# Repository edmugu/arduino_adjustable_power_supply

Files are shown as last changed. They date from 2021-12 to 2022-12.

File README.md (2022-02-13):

---
title: Intro
nav_order: 1
description: "Just the Docs is a responsive Jekyll theme with built-in search that is easily customizable and hosted on GitHub Pages."
permalink: /
---

# [Arduino Power Supply](https://edmugu.github.io/arduino_adjustable_power_supply/)

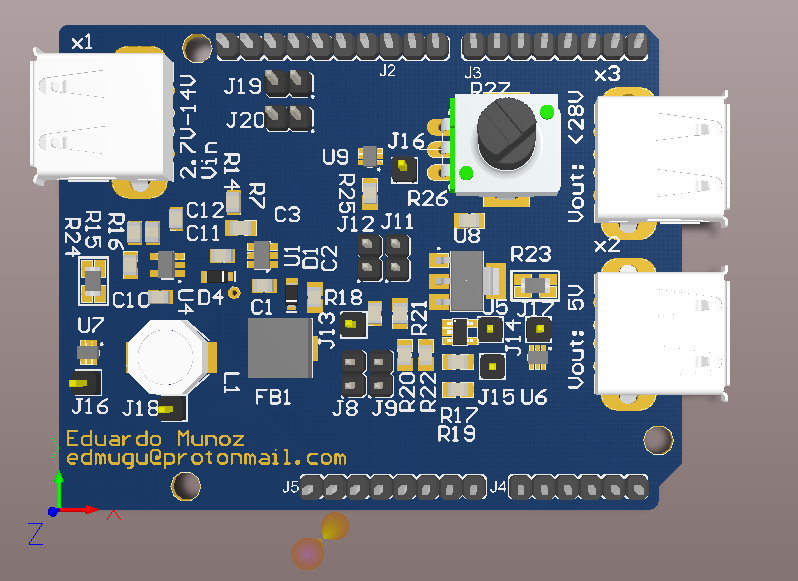
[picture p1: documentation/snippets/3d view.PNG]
3d view of pcb file Power Supply


link to Jekyll readme: https://edmugu.github.io/arduino_adjustable_power_supply/

## Abstract

This project is based on the [LT journal's Article from Keith Szolusha](https://github.com/edmugu/arduino_adjustable_power_supply/blob/master/documentation/LTJournal-Bench_Supply.pdf). In the article, he discussed how to design a clean power supply. However, this design is augmented by making it controllable by an Arduino. Use Cases Include motor controller, high power wireless communication, and benchtop supply.

## Intro

On the original design by Szolusha, there are four modules. (1) a switching regulator that steps down a 10-40V input to an intermediate voltage that is slightly above the output voltage. (2) Linear regulator that "cleans" the output. (3) The current source sets a reference voltage that is not affected by temperature. Lastly, (4) A current sink that helps the Linear regulator reach low voltages.

We will modify each block to fit our needs, making this portable and usable with any common household batteries. So the base design is shown on the diagram below. The first step is to step up the battery's voltage to a usable voltage we can step down. The second step is to step down the voltage to the wanted voltages like 3.3 Volts, 5.0 Volts, and Vout. However, the efficient step-down switches can create "switching ripples" on the output. These ripples aren't a big deal; however, one could use an inefficient LDO regulator if one needs a very clean supply. So will use the step-down switch and regulator to create a clean semi-efficient voltage output as shown on the diagram.

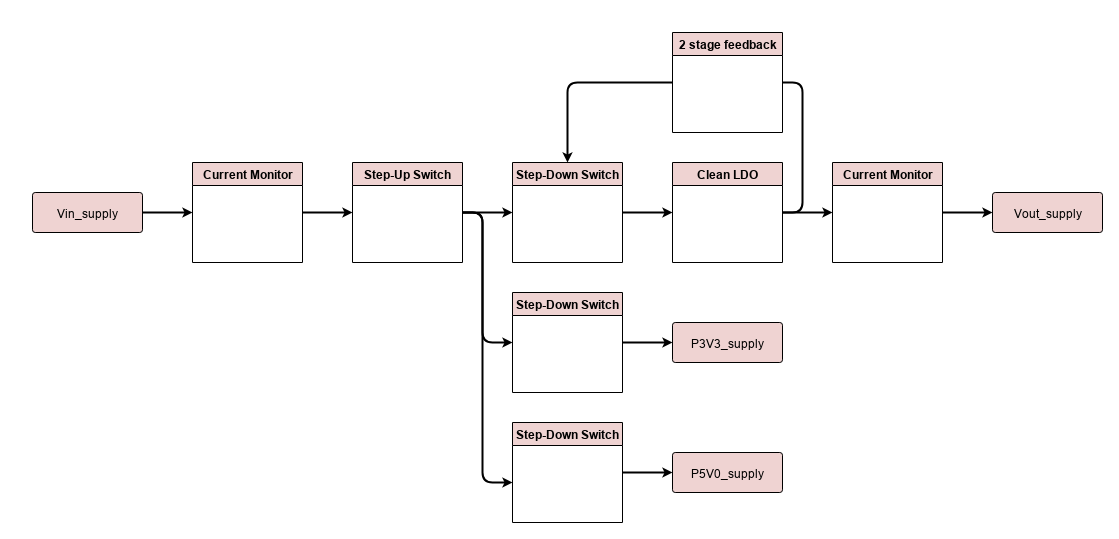
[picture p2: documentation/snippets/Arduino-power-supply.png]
logic schematics


The main target battery is a USB power bank. Most USB power banks can deliver 12W @ 5Volts. Hence, this power supply will deliver 10 Watts at its output to accommodate the inefficiencies of the power stages of this design. Since the default use case will power a 50-ohm load, the maximum voltage at the output should be greater than 22.36 Volts to deliver 10 Watts.

## Disclaimer

I initially was practicing my PCB making skill by testing this "dummy" idea of hooking a 1-amp boost to a 1-amp buck to a 1-amp linear regulator. However, while I was finishing with this PCB of a "dummy" idea that was not really tested, the hardware team I was part of got laid off but I was rehired a few days later. None the less, during those days I though of just manufacturing this PCB and documenting my hardware debugging skills. So there were plenty of bugs on Rev A. Anyhow I am thankful of these series of events, that made me realize how important is to have "demo" projects you can show your future employer.

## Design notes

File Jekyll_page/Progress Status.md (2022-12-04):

---
title: Progress Status
has_children: no
nav_order: 6
---

At the moment I am verifying the the Rev B0 board

2022_12_03: started testing Digital pots and vref.

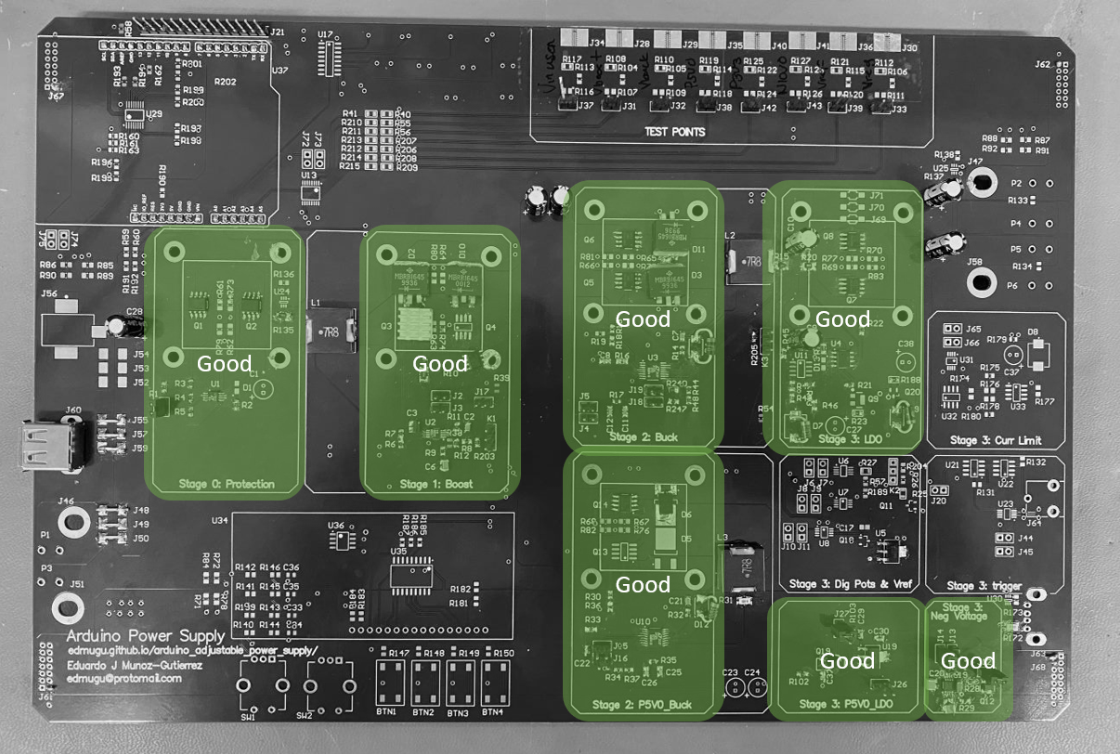
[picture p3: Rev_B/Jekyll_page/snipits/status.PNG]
status diagram


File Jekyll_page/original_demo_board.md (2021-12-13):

---
title: Original_demo_board
has_children: no
nav_order: 5
---

While doing tests on my board, I wanted to compare my design to the reference design shown in the article. So I decided to look for demo boards for the same components used in the article. AND I COULD NOT BELIEVE IT!!! I found the original board still being sold on mouser.com. So I bought one to be able to compare it to my board. Even after getting the board, I was still in denial, the article was written in the summer of 2014, and the demo boards were still being sold in 2021. 

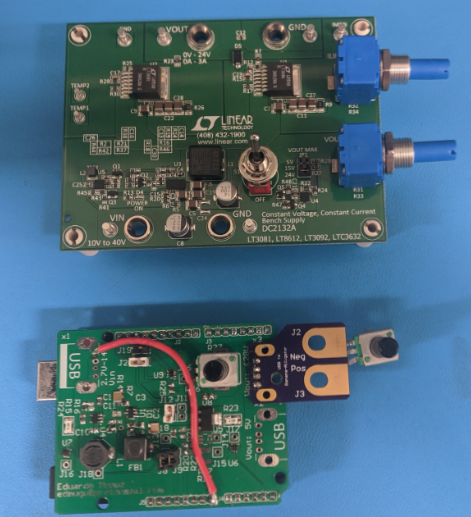
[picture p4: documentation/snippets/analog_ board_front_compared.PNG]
demo board front the front of the demo board


This made me feel great since I was able to tell that Analog Devices needed 3 revisions of this board to get this [simple design] right.

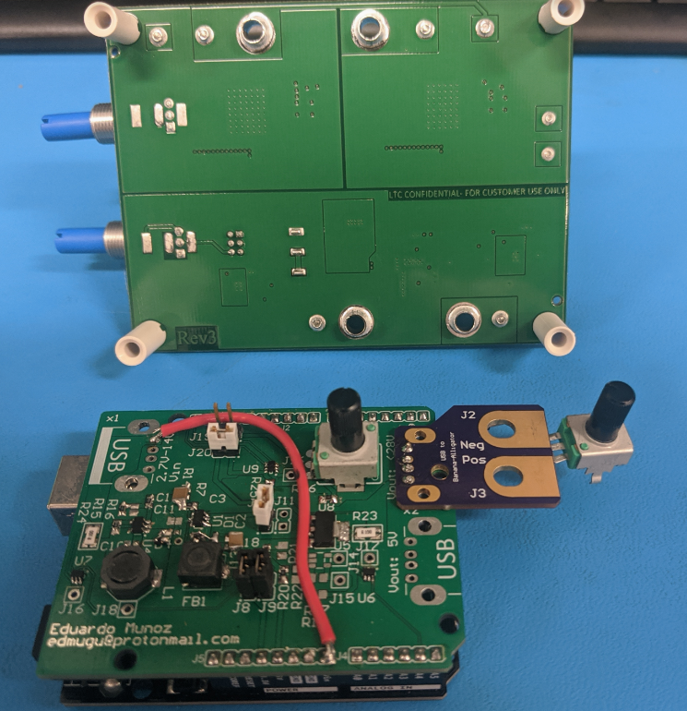
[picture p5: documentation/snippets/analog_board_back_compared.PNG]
demo board back the back of the demo board


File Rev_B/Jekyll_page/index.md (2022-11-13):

---
title: Rev B0
has_children: yes
nav_order: 4
has_toc: false
redirect_to: https://edmugu.github.io/arduino_adjustable_power_supply/Rev.%20B/Jekyll_page/Updates.html
---

This is my second attempt at my power supply, and I corrected the issues described on the "design flaws" and "debugging" pages of rev. A

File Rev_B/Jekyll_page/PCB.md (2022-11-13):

---
layout: default
title: PCB
nav_order: 4
parent: Rev B0
---

# PCB

Before I picked any case, I wanted to "modularize" each stage to know how much space I needed. Also, to get better temperature readings of the MOSFET, it seems that having two MOSFETS in "parallel" would distribute the heat propagated. And a thermal resistor could be placed in between, with some thermal paste; that way, the temperature readings would be more accurate. 
Currently, 2 inches x 2 inches will be good enough per stage [not counting the heat sink area]. So I will probably need a case 10 inches x 4 inches. 

## Thermal sensors

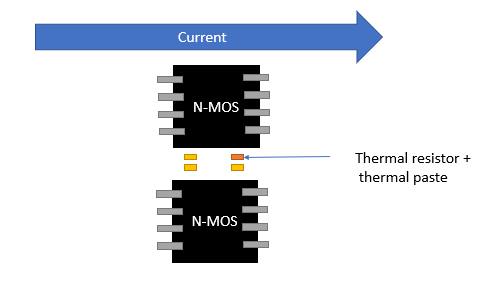
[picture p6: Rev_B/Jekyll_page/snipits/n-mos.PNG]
n-mos


In addition to having a single thermistor circuit, there will be another pair of resistors as a reference. That way, a differential pair can be made, and the measurements will be more accurate. 

## Test points

I have wanted to add proper "high speed" test points that are 50 ohms, so I could hook a high-end scope to the various design stages. Since connecting the 50-ohm probe to the voltage rails would overwhelm the controllers/regulators, I used a π-matching circuit. The image below shows such a circuit below. Note that even R48 is not needed; I left it for "good luck/practice." 

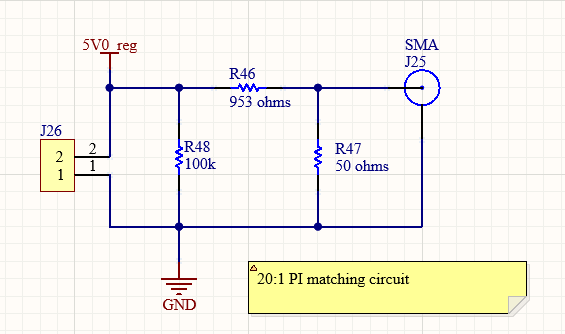
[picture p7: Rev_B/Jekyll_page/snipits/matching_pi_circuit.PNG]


## Encoders instead of Potentiometers

I have also been wanting to add encoders since they have an unlimited turn count—one for voltage and one for current limit. 

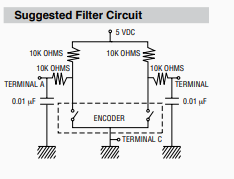
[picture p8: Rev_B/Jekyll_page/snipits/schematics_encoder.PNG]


## The first draft of the PCB  

The first loose draft of the PCB seems to be 37cm long and 26 cm wide. So a nice aluminum case that is 21 cm long and 10 cm wide could be the target size after I clean stuff up. 

### Front

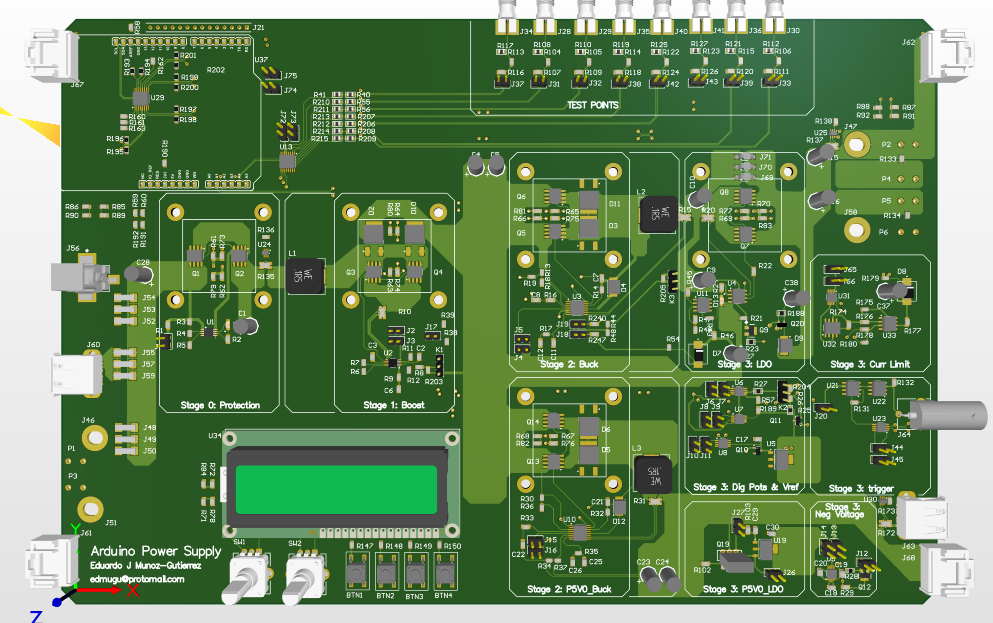
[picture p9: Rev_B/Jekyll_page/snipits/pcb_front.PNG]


### Back

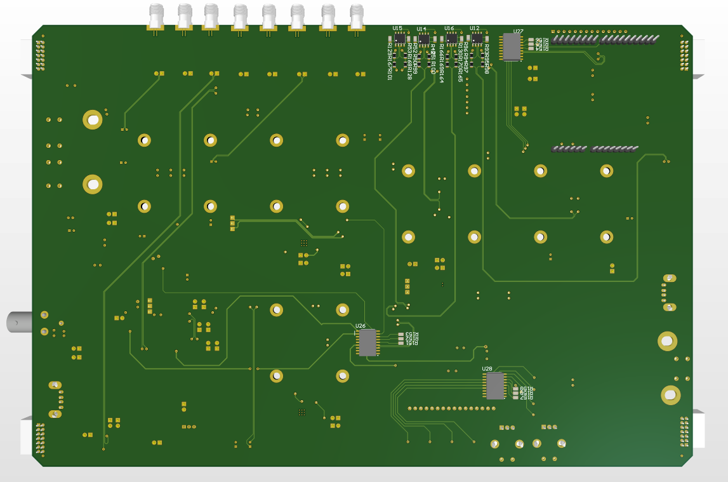
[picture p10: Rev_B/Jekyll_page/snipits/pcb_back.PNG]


## Case

The case chosen is [linked here](https://www.digikey.com/en/products/detail/rose-enclosures/07504011/7802327)

 The inner dimensions for the PCB are 200.6 mm x 300 mm

## Final PDFs

https://github.com/edmugu/arduino_adjustable_power_supply/blob/master/Rev_B/Jekyll_page/PCB.pdf

<object data="https://github.com/edmugu/arduino_adjustable_power_supply/blob/master/Rev_B/Jekyll_page/PCB.pdf" width="1000" height="1000" type='application/pdf'></object>

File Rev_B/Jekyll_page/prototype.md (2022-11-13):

---
layout: default
title: Prototype
nav_order: 3
parent: Rev B0
---
## Bread board prototypes. 
I started doing sanity checks on my breadboard before designing the PCB. Moreover, even though I could not run them at high power [as shown below]. It revealed some of the design issues I should have caught in the simulation phase.  
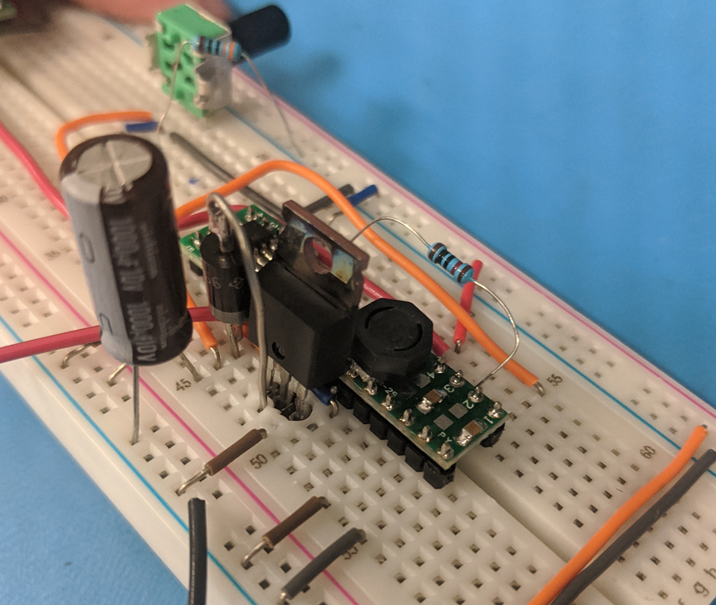
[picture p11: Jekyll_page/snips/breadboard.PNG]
Burned BreadBoard Very Hot Transistor


## Issue Solved #1: TI's voltage regulator below 1.2V requires a minimum current 

When I breadboarded this with an adjustable linear regulator that can only push current, the output never went below 1.2 V. The reason is that when the Vref_ext is held above 1.2 V, the Reg will start to "shut down" and leave the output pin floating. So the output will be the same as Vref_ext since there is no current across R_bot and R_top. To overcome this, one needs a minimum current at Vout to drop 1.2V across R_top. 

Also, since the voltage will be either controlled by external resistors OR the external voltage reference. The regulator will have to switch between these two modes of operation. If the desired voltage is above 2.4 V, the external resistors will control the regulator, and it will behave like a normal regulator. However, if the desired voltage is below 2.4V, it will slowly turn on Vref_ext, keeping R_top and R_bot the same. This will force the main regulator to shutdown.  

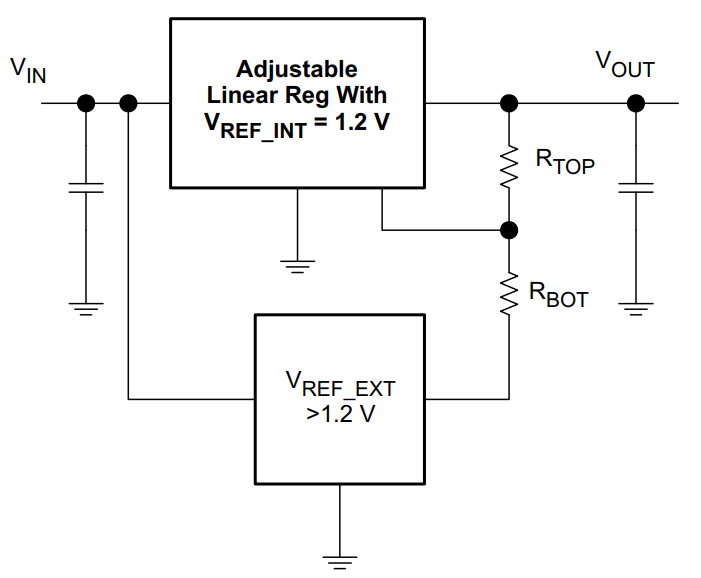
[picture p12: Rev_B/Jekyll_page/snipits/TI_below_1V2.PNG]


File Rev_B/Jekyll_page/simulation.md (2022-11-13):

---
layout: default
title: Simulations
nav_order: 2
parent: Rev B0

---

# Intro to the Simulation study 

In short, I have learned that to design a power circuit right, you have to use the SPICE tools of the PROs [i.e., Texas Instruments and Analog Devices]. This is because their tools will have the proper model for the components they sell and the supporting components they use to test their devices. So their SPICE simulations will be far better than the ones that average engineers can do by importing models or making pseudo models of the components they plan to use. 

The following are the simulations "learning nuggets" I have come across with that out the way. 

## Issue Solved #1: External Reference too noisy

In the beginning, it seemed that hooking Vref_ext as a voltage divider and voltage buffer would be a good idea. However, it turns out that the noise of Vin and voltage buffer "noise" can get in Vout. So buffer would not be a good idea. So Vreg_ext had to be a linear regulator. 



## Issue Solved #2: LT1575 with "virtual ground"

During simulation, it was found that the gate driver is not directly connected to the ground; therefore, the gate will always be held above ~2.0 Volts. Unfortunately, this will not allow you to output a voltage below 1.2V even if you use the "TI's external voltage reference" modification.

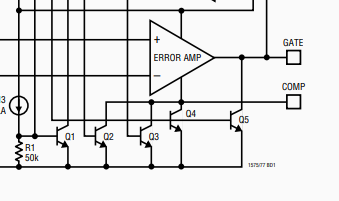
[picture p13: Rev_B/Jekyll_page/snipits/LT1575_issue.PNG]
LT1575 virtual ground


So I will have to use a part, not from analog devices. However, the MIC5156 does have a gate driver capable of going down to 1 volt at the gate voltage. And even though Vout_low is not zero volts, there are plenty of MOSFETs with a gate threshold above 1 volt. 

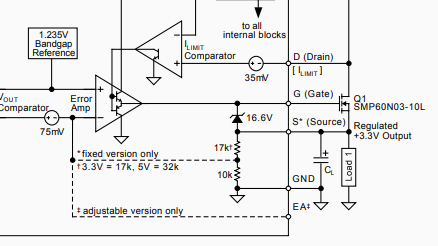
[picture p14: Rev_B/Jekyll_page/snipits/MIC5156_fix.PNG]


## Issue Solved #3: Proper Capacitor 

During the simulation, I discovered why the Tantalum capacitor is bad for power supplies. The reason is that these capacitors have an "equivalent series resistance" around a few ohms. So one can only draw a few amps with a significant voltage drop. That is why you should use Aluminum Electrolytic Capacitors since their ESR is in the milliohm range. 

## Issue Solved #4: Power filter

For the reference voltage, I wanted to pre-clean the ripples from stage 1 to ease the regulator's job. Moreover, I found that active filter #1 was the best choice of the three proposed designs. 

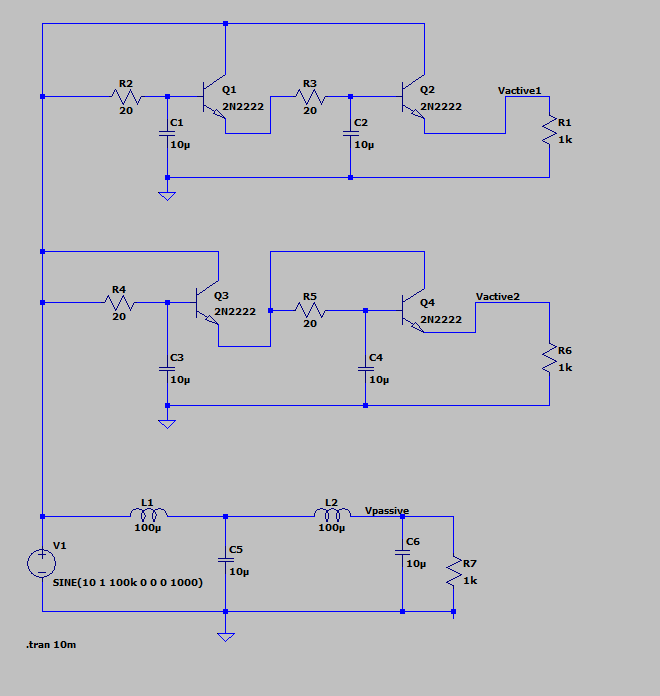
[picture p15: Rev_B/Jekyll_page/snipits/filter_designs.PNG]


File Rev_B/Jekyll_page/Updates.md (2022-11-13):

---
layout: default
title: Rev. B Updates
nav_order: 1
parent: Rev B0
---

# Simulation Updates

For this revision, there have been more simulations for all the subcircuits. Moreover, to guarantee real-life performance, I decided to use LTspice, the simulator from "Analog Devices"/"Linear Technologies." They already have proper models for their device portfolio, so it would be easy to use this for this project. 

# Hardware Updates

## (1) Regulators vs. Controllers

After debugging Rev. A, I noted that at the moment, there was no IC sold in Digi key that could output over >= 2 amps **with the same package**. That is when I realized that voltage controllers are more upgradeable than voltage regulators. The reason is that a voltage regulator is a voltage controller WITH a power transistor and current sense mechanism. So if you want to upgrade your voltage controller power supply to handle more power, you just update the power transistor and current sense mechanism. Moreover, if you want to upgrade a voltage regulator, you hope there is an IC with the same package that meets your requirements. 

Also, while designing Rev A, I realized that the final linear voltage regulator that used an **LM317** could be more efficient. Since it requires at least a 3-volts difference between the input and the output. And voltage controllers can have a smaller voltage drop between their input and output

## (2) Reverse Voltage Protection

This is something that was not included in Rev. A at all, and it is important. 

## (3) Minimum voltage output

The minimum voltage output most voltage regulators can output is its internal reference voltage level. So most regulators can't go below 1.2 Volts by themselves. And this bothers me since the reference design from Linear Technologies can be to 0 volts. Then I found this article from Texas Instruments on how to tackle this issue which is [linked here](https://github.com/edmugu/arduino_adjustable_power_supply/blob/master/documentation/TI_Below_1V2.pdf) .  The article derives the equation shown below. 
$$
Vout = V_{REFint} * (1+ \frac {R_{TOP}}{R_{BOT}}) - (\frac{R_{TOP}}{R_{BOT}}*V_{REFext})
$$
The plan would be to operate Vout normally when Vout > 2.4 Volts. But for Vout < 2.4 the Vrefext would be used to adjust the voltage instead of the resistor ratio. That scenario leads to the following equation: 

$$
Vout = V_{REFint} * 2 - V_{REFext}
$$
which practically means that the average of Vout and Vrefext has to be 1.2Volts

$$
\frac{Vout+V_{REFext}}{2} = V_{REFint} = 1.2 [volts]
$$

So if one varies Vref from 0 to 2.4 Volts it will vary Vout from 2.4 to 0 volts. 

## (4) Trigger/Soft-starter

To add a trigger and soft start, I wanted to add a tap that would control Vrefext. But to make it easier for the user this tap would take an input between 0 and 1 volt to represent 0% to 100% of the voltage set.  That would leave to the following equation where k is pre-gain on the Vtap. 

$$
Vout = V_{REFint} * (1+ \frac {R_{TOP}}{R_{BOT}}) - (\frac{R_{TOP}}{R_{BOT}}*k*V_{tap})
$$
So to simplify the equation, 

$$
Vref*(1 + \frac{R_{TOP}}{R_{BOT}} )= \frac{R_{TOP}}{R_{BOT}} * k
$$
if we solve for k

$$
k = Vref * (\frac{R_{BOT}}{R_{TOP}} + 1)
$$

## (5) Sense ports

Sense ports were added to take into account the voltage drop on the wires.

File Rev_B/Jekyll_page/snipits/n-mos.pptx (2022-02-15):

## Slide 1

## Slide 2

Current

N-MOS

N-MOS

Thermal resistor +
thermal paste

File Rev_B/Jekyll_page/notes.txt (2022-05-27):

board regions

     ┌──────────────────────────────────────────────────────────────────────────────────────┐
     │                                                                                      │
     │         ┌──────────┐     ┌───────────────────────┐    ┌──────────┐                   │
     │         │e2        │     │                       │    │          │                   │
     │         │          │     │                       │    │          │                   │
     │         │          │     │ Text points           │    │ S2D      │                   │
     │         │          │     │                       │    │          │                   │
     │         │          │     │ e10                   │    │          │                   │
     │         └──────────┘     └───────────────────────┘    └──────────┘                   │
     │                                                                                      │
     │                                                                                      │
     │                                         ┌──────────┐   ┌─────────┐                   │
     │                                         │          │   │         │                   │
     │           ┌───────────┐  ┌─────────┐    │          │   │         │                   │
     │           │           │  │         │    │          │   │         │                   │
     │           │           │  │         │    │          │   │         │    ┌───────────┐  │
     │           │           │  │         │    │          │   │         │    │           │  │
     │           │           │  │         │    │          │   │         │    │           │  │
     │           │           │  │         │    │          │   │         │    │           │  │
     │           │           │  │         │    │          │   │         │    │           │  │
     │           │           │  │         │    │          │   │         │    │ S3F       │  │
     │           │           │  │         │    │ S2a      │   │ S3a     │    └───────────┘  │
     │           │           │  │         │    └──────────┘   └─────────┘                   │
     │           │           │  │         │                                                 │
     │           │S0A        │  │S1A      │    ┌──────────┐                  ┌───────────┐  │
     │           └───────────┘  └─────────┘    │          │    ┌─────────┐   │           │  │
     │                                         │          │    │         │   │           │  │
     │             ┌──────────────────────┐    │          │    │S3BC     │   │           │  │
     │             │ E6&9                 │    │          │    │         │   │ E4        │  │
     │             │                      │    │          │    └─────────┘   └───────────┘  │
     │             │                      │    │          │                                 │
     │             │                      │    │          │                                 │
     │             │                      │    │          │                   ┌────┐        │
     │             │                      │    │          │    ┌───────────┐  │S3D │        │
     │             └──────────────────────┘    │ S2B      │    │ S2C       │  │    │        │
     │                                         └──────────┘    └───────────┘  └────┘        │
     │                                                                                      │
     └──────────────────────────────────────────────────────────────────────────────────────┘

GPIO regions:
	backward view of IC

	9:GP1		10:GP2
	8:GP0		11:GP3
	7:INT		12:GP4
	6:RST		13:GP5
	5:ADD		14:GP6
	4:SDA		15:GP7
	3:SCL		16:NC
	2:NC 		17:NC
	1:VDD		18:VSS

	region 0:
		E6 UI signals
	
	region 1: 
		e2 temp sense
		e10 voltage sense 
		s2d Feedback select

I2C regions

	Region 0: back panel [fan motor?]
		SD0 		back panel 
		
	Region 1: User input and 
		SD1	U28	GPIO  		User input
		SD1 	U35 	DISPLAY
		SD1 	U36 	eeprom

	Region 2: Stage 3 digital pots and GPIO 
		SD2 	U6/U7 	digital pot voltage
		SD2 	U26/U27	GPIO

	Region 3: Stage 3 extras
		SD3 	U8 	digital pot vref
		SD3 	U31	digital pot ilimit

	Region 4: Stage 3 extras and front panel
		SD4 	U23 	dig pot trigger
		SD4 		front panel

GPIO extender regions

https://www.digikey.com/en/products/detail/advanced-thermal-solutions-inc/ATS-CPX025025015-138-C2-R0/4754010

https://www.digikey.com/en/products/detail/advanced-thermal-solutions-inc/ATS-HK127-R0/4809539

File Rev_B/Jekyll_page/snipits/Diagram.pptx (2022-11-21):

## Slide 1

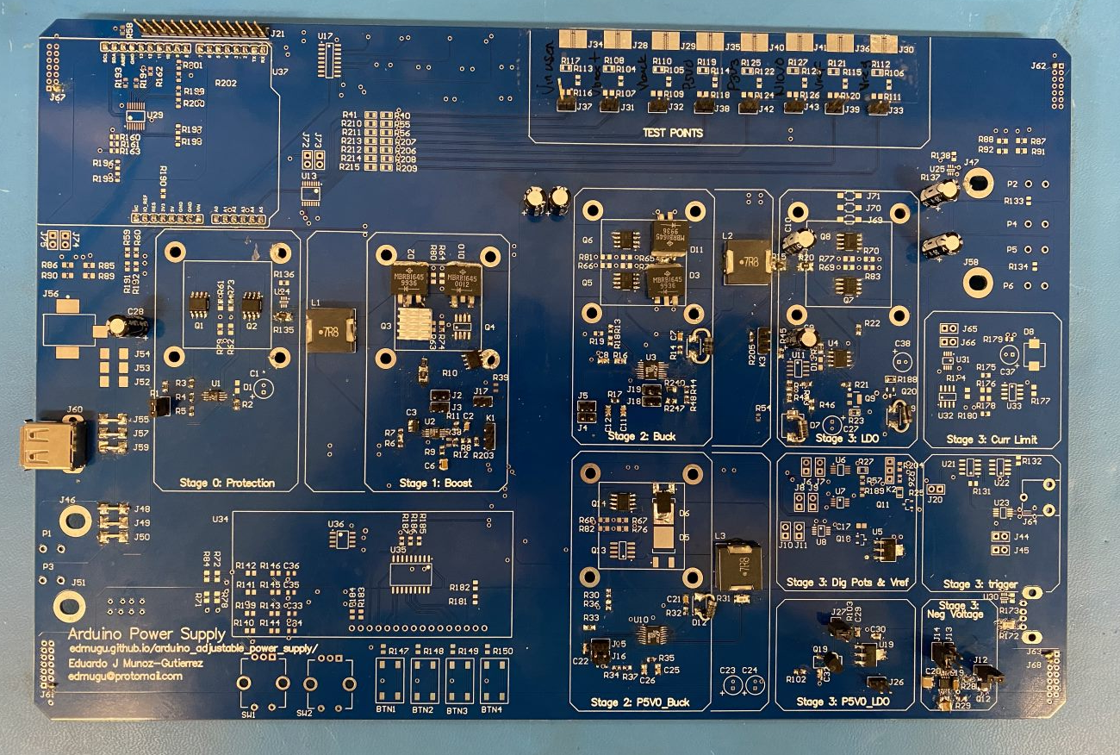
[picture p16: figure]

Good

Good

Good

Good

Good

Good

Good

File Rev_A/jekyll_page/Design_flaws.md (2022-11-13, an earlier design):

---
title: Design Flaws
has_children: no
nav_order: 7
parent: Rev A0
---

# Design Flaws

## How much current can be drawn in and drawn out

The main mistake I made was on the step-up stage. I expected this stage to be able to handle 1 amp current since the datasheet of the step-up regulator mention that this was a **"40Vout, 1A Step-Up voltage regulator."\** However, current can only be achieved when the output voltage is close to the input voltage, as shown in the figures below. Now in figure 10, one can see that when the input voltage is 3.3Volts, and the output voltage is 15Volts, the output current will be less than 200 mA. The reason is that the regulator can only handle 1 Amp. So it can only output the 3.3 Watts it gets in [ = 3.3 Volts * 1 amp]. This means it can only deliver a maximum of 0.22 Amps [= 3.3 watts / 15 volts ]. And in top of that the regultor is >60% efficent at that point so one would only get  0.132 Amps [= 0.22 Amps * 0.60].

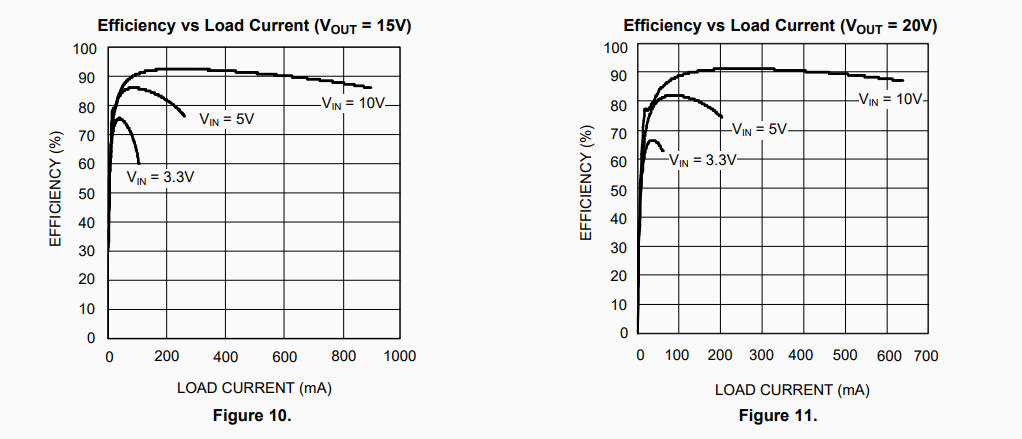
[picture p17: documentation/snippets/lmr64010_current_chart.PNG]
LMR64010 current chart


So if I wanted a regulator that could deliver 1 amp at 36 Volts, I would have needed a regulator that could handle >36 Watts at its lowest voltage of 2.7 Volts, which means that the regulator needed to handle at least 13.333 Amps. Unfortunately, the power banks I have seen can only handle a max of 2.1 - 3 Amps so I going to limit the current to that.

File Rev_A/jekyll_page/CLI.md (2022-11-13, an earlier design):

---
title: CLI
has_children: no
parent: Rev A0
nav_order: 5
---

# Command Line Interface

The easiest way to monitor voltage is to use the Arduino Firmata library. The Arduino IDE can easily upload this by opening the firmata project and uploading it to the Arduino. Afterward, you can run the /python/read_voltage.py script provided in this report.

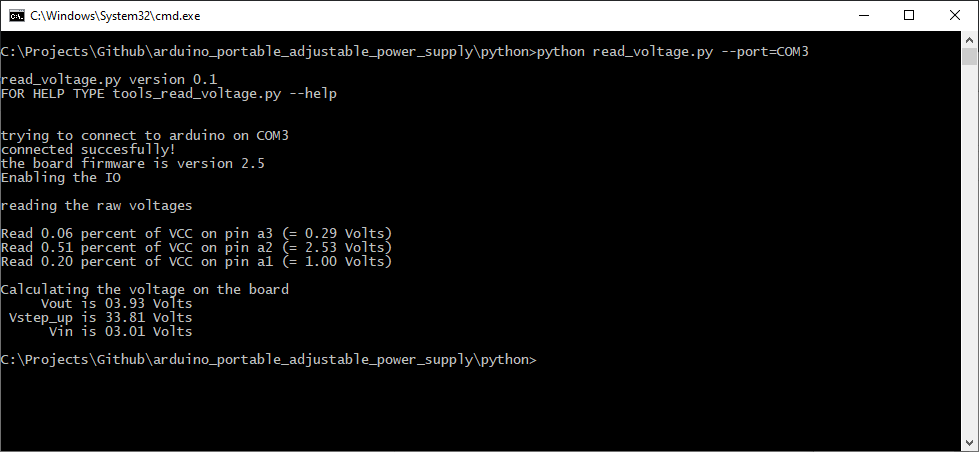
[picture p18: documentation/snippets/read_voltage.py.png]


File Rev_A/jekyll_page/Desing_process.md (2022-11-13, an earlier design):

---
title: Design Process
has_children: no
parent: Rev A0
nav_order: 1
---

# Design process
## Use cases
Before we design anything, it is better to set some use cases to come with some characteristics our design must meet.

Input battery

| Use Case | Voltage [V] | Current [A] | Power [W] | Notes |
|---|---|---|---|---|
| AA | 1.5 | 0.050 | 0.075 | This voltage might be too low |
| 9-Volt | 9 | 0.111 | N/A | Forced Power to 1 Watt |
| CAR | 12.6 | 0.793 | > 10 | |
| Power Bank | 5 | 2.4 | 12 | |

Output Use cases

| OUTPUT | Ideal | Max |
|---|---|---|
| Power | 0.1 Watts | 11 Watts |
| Current | 0.1 Amp | 1 Amp |
| Voltage | 5 Volts | 23 Volts |
| LOAD | 50 Ohms | NA |

## Pre-requirements
Now that we have all our use cases (and an ideal use case), we can start defining some requirements for our design. 

Input: 	1.0 Volts to 14 Volts

Output:	0-23 Volts

Power:	< 10 Watts [depending on the battery]

Monitors:
	* Voltage, for all the stages of the regulator
	* Current, for the input and output stages

Controls: 	
* Manual, with the help of a potentiometer
* Automatic, with the help of digital resistors

Communications:
* I2C
* USB COM port (provided by Arduino with the [Firmata library](https://www.arduino.cc/en/reference/firmata) )

Versions:
* stand-alone
* Arduino addon

## Design Procedure
### (1) Battery Current Monitor stage
The input batteries used might have a current limit (i.e., the maximum current will be 2.4 Amps as the typical use case). This will be done to ensure the life of the battery. The first step will be to measure the current going into the device. This can be done with a current monitor with a voltage range from 0 to 14V and can detect <2.4 Amps through a sense resistor. The INA199 meets the voltage range requirement, and it has an x200 gain.
R_Sense should be less than 1 ohm since it will have up to 1 Amp going through it. However, it should be high enough to detect the voltage drop. Therefore, we installed a 100mOhm sense resistor with four terminals. We could have picked a smaller resistor, but we stuck with that value since a cheap Arduino will most likely read this. Further, to avoid measuring the voltage drop across the solder pads, we installed a four-terminal resistor.

| | Voltage | Notes |
| --- | --- | --- |
| Input  | -0.3 to 26 V | |
| Output | Vin - 0.24 V | worse case @ I = 2.4 Amps |

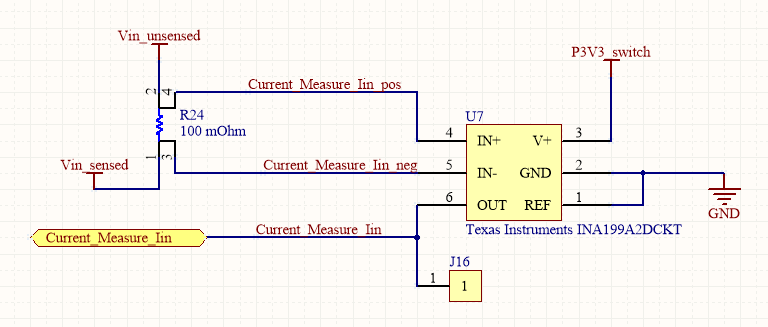
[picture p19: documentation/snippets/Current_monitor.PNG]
Schematics of the current monitor Current Monitor


### (2) Step-Up stage
Instead of using an expensive step-down/step-up converter to do all we need, we opted for a cheap two-stage module. We first need to step up the voltage above the maximum output voltage [ to account for inefficiencies]. That way, we can take any battery as the input, no matter its voltage. The IC **LMR64010** will be used for this module. Its maximum output voltage is 40V, which is well above the wanted 23V output. Therefore, its power output is 40 Watts when the regulator is set to output 40 Volts. However, the battery can limit this stage if the battery cannot deliver 40 Watts. Further, this IC has the disadvantage of only taking voltages from 2.7V to 14V. Hence, we can update our requirements only to take voltages as low as 2.7 Volts.

| | Voltage | Current | Notes |
| --- | --- | --- | --- |
| Input  | 2.7 to 14 V | | |
| Output | <40 V | <1 A | ~85% efficiency |

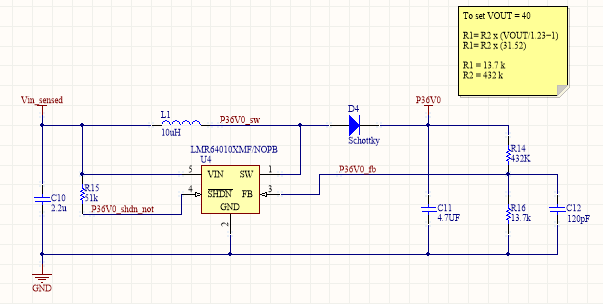
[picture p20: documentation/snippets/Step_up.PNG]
Schematics of the Step-Up stage Step-Up stage


### (3) Step-Down stage

#### (3A) Step-Down switch substage
The previous stage will output a voltage of up to 40 Volts. However, the final output needs to be above 23 Volts. The IC **AOZ1282CI** is a cheap buck converter that takes up to 36 Volts. It can reduce the voltage from 0.8 V to 85% of the input voltage. If I want to output 23 Volts, I need at least [Vout = 0.85 Vin OR Vin = 23/.85] 27 Volts. Hence, 36 Volts is good enough to give me some wiggle room. Note that output voltage should be slightly higher than the final output voltage to count for inefficiencies in the next stage. Therefore, the feedback circuit has to feed on the next substage. Further, I can keep this stage to the maximum voltage needed of 27 Volts [ + some wiggle room].

| | Voltage | Current | Notes |
| --- | --- | --- | --- |
| Input  | 4.5 to 36 V | | |
| Output | 0.8 to 85% Vin | <1.2 A  | efficiency >85% |

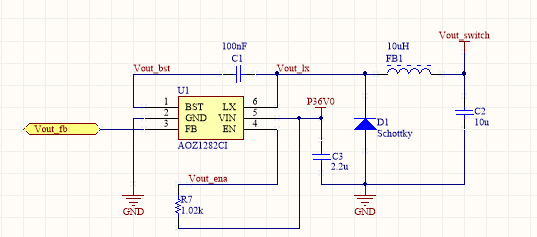
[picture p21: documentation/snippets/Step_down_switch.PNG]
Schematics of the Step-Down Switch Step-Down switch


#### (3B) Step-Down Linear Regulator substage

The second substage is used to clean any noise created on the step-down switch. Now the **LM317** is an adjustable linear regulator that can output over 1 Amp and take in up to 40 Volts. This meets our needs effectively.

| | Voltage | Current |
| --- | --- | --- |
| Input  | 4.25 to 40 Volts | |
| Output | 1.25 to 37 Volts | <1.5 A  |

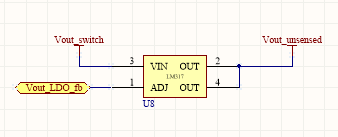
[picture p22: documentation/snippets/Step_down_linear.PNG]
Schematics of the Step-Down linear regulator Step-Down linear regulator


#### (3C) Feedback to substages

The main challenge is that the first substage's voltage should be above the output of the second substage. However, if the difference in the voltage between the two is too high, the second stage will have to "overburn" the excess voltage, making it less efficient. On top of that, the final voltage is adjustable. To tackle this, an operational amplifier is used to calculate the voltage difference between the stages. This voltage will be fed to the second stage [the switching regulator], which will raise its voltage until its feedback reaches its critical voltage. Hence, the voltage of the switching regulator will be held above the final output.

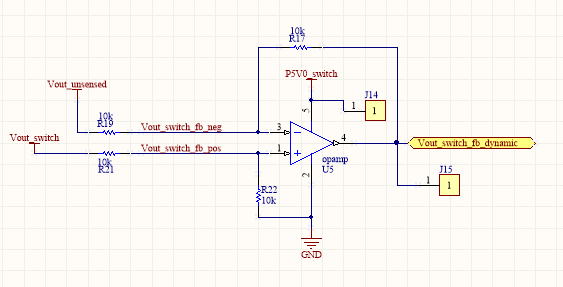
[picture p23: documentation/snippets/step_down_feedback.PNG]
Schematics of the feedback circuit feedback circuit


### (4) Final Battery Current Monitor stage

This is the final stage of the power supply. By having a current monitor at the beginning and the end, we can calculate the power supply's efficiency. Also, the feedback voltage of the previous stage takes the drop across this stage by feeding the "final" voltage to the linear regulator. 

### (5) Arduino Control 

 To make the design controllable by an Arduino, an I2C digital pot was added to one of the choose-able feedback circuits. 

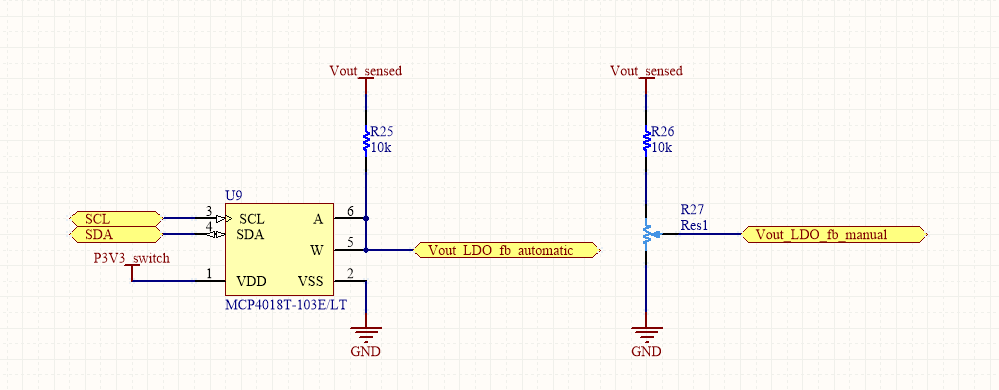
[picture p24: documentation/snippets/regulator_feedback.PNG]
regulator_feedback


## Test validation

To guarantee that the board works and can be massed produced, some basic validation tests have to be set. These should include software and hardware test, [which are described on the wiki with more details](https://github.com/edmugu/arduino_adjustable_power_supply/wiki/Hardware-Test-procedure)

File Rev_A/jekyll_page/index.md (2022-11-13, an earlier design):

---
title: Rev A0
has_children: yes
nav_order: 3
has_toc: false
redirect_to: https://edmugu.github.io/arduino_adjustable_power_supply/Rev.%20A/jekyll_page/Desing_process.html
---

This project is my first attempt at the power supply. And I have made mistakes like one should expect. However, there was a fundamental mistake that I have made that intrigued me the most. That is my calculation on how much current my power supply can deliver. This mistake is further explained on the page "design flaws."

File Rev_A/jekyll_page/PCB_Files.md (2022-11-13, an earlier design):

---
title: PCB Files
has_children: no
parent: Rev A0
nav_order: 4
---

All PCB files can be found on the link below. 

You could also access them here: https://365.altium.com/files/CA072D2F-C92D-11EB-A2F6-0A0ABF5AFC1B 

<iframe frameborder="0" width="375" height="365" scrolling="no" src="https://circuitmaker.com/Projects/Details/Eduardo-Munoz-Gutierrez/Arduino-Portable-Power-Supply/embeded"></iframe>

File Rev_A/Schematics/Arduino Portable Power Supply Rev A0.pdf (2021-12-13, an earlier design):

# PAGE 0 -- Logical Schematics

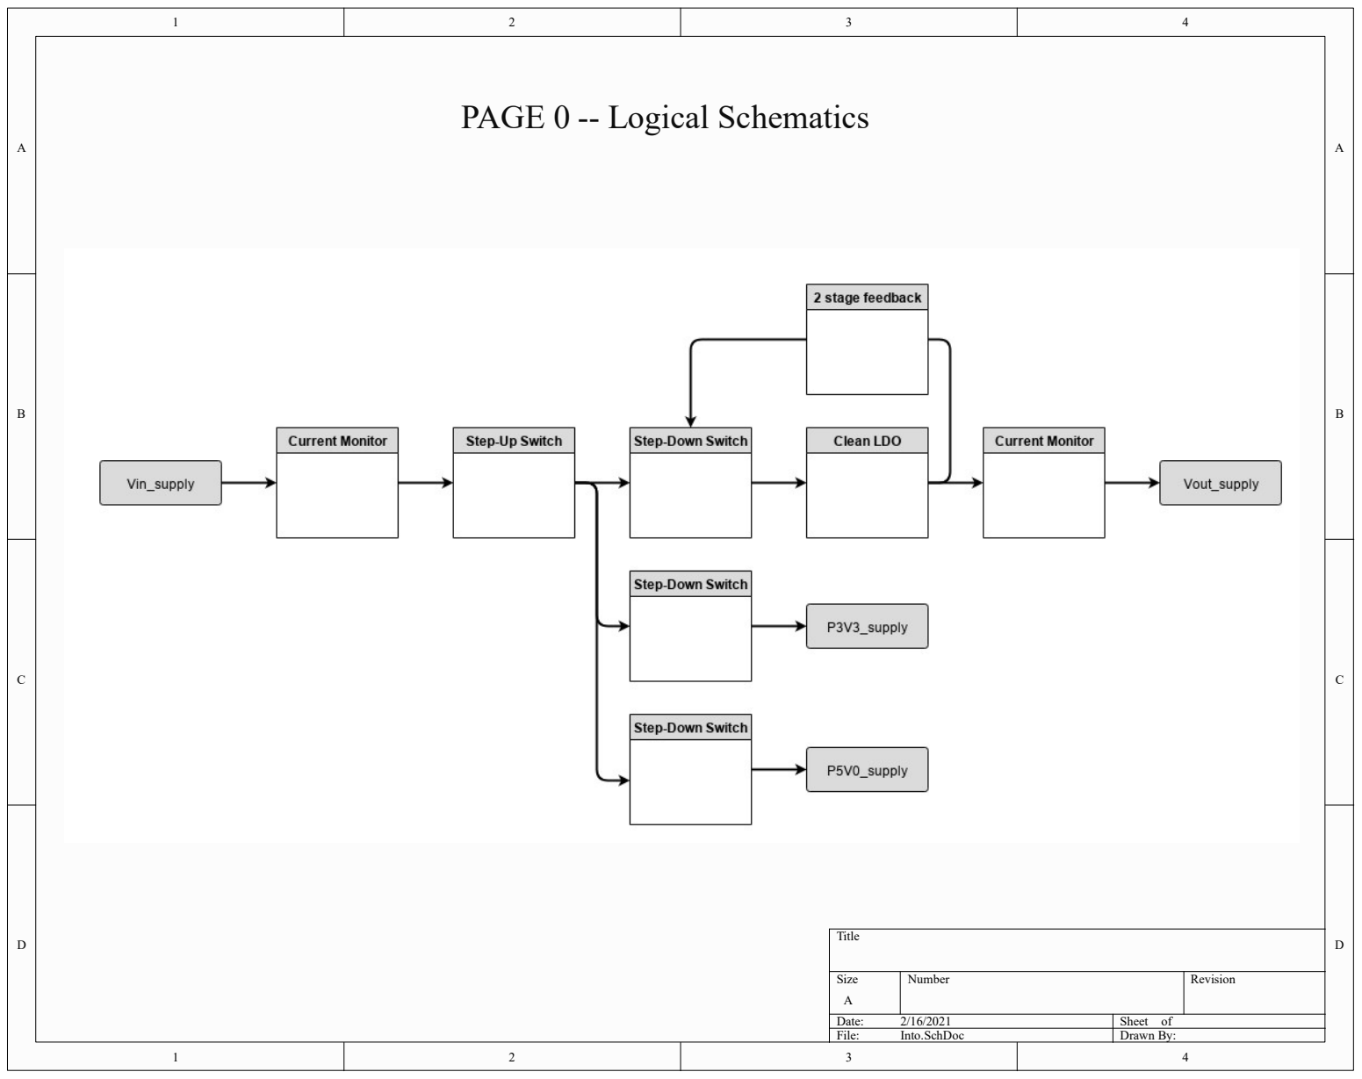
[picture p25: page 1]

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
Title

Size | Number | Revision
A
Date: | 2/16/2021 | Sheet of
File: | Into.SchDoc | Drawn By:

# PAGE 3 -- Step-Down Switch

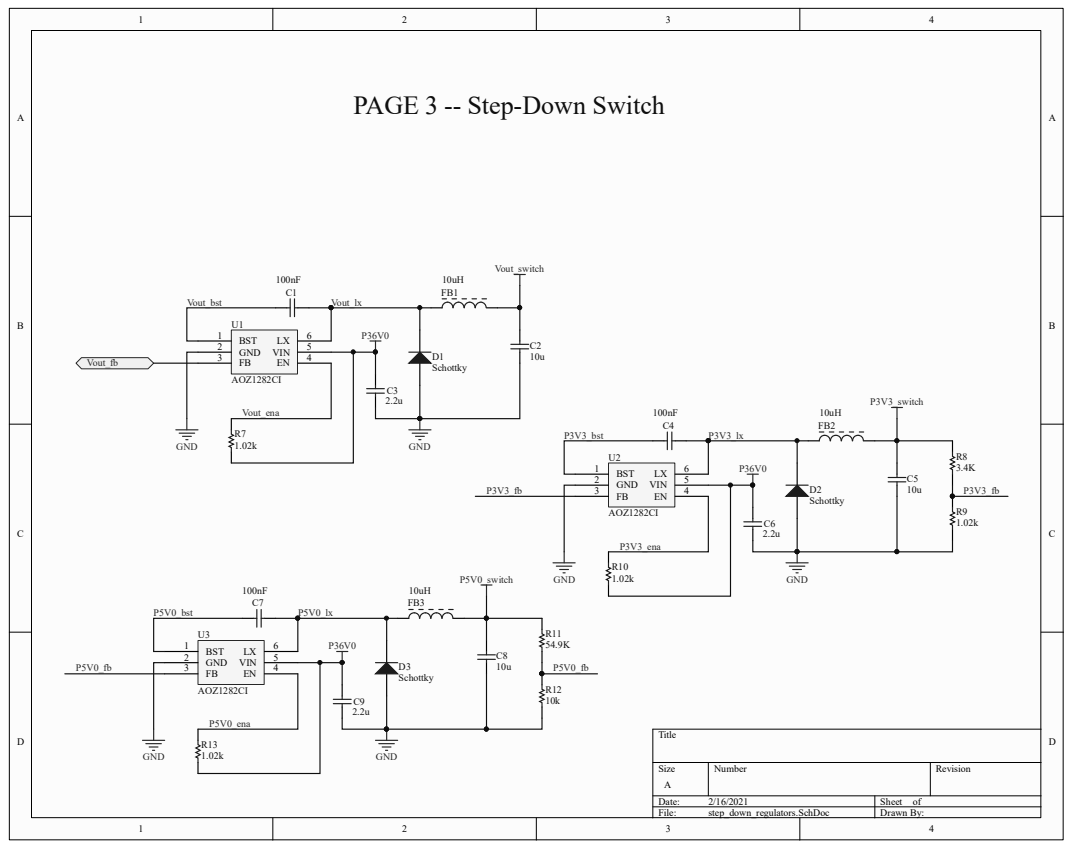
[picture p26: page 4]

# PAGE 6 -- Current Monitors

Title; Size; Number; Revision; File:; current_measure.SchDoc; Drawn By:; REF; GND; OUT 6; Texas Instruments INA199A2DCKT; Vin_unsensed; Vout_unsensed; 100 mOhm; Vin_sensed; Vout_sensed; P3V3_switch; Current_Measure_Iin; Current_Measure_Iout; Current_Measure_Iout_pos; Current_Measure_Iout_neg; Current_Measure_Iin_pos; Current_Measure_Iin_neg

# PAGE 7 -- IO

Title; Size; Number; Revision; File:; inout.SchDoc; Drawn By:; P3V3_switch; GND; Vin_unsensed; P5V0_switch; Vout_sensed; VBUS; USB PORT

TE Connectivity / AMP 292303-1

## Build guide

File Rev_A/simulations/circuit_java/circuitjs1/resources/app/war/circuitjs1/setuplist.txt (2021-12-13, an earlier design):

### setuplist.txt first line must be a comment
+Basics
ohms.txt Ohm's Law
resistors.txt Resistors
cap.txt Capacitor
induct.txt Inductor
>lrc.txt LRC Circuit
voltdivide.txt Voltage Divider
pot.txt Potentiometer
potdivide.txt Potentiometer Divider
thevenin.txt Thevenin's Theorem
norton.txt Norton's Theorem
-
+A/C Circuits
capac.txt Capacitor
inductac.txt Inductor
capmultcaps.txt Caps of Various Capacitances
capmultfreq.txt Caps w/ Various Frequencies
indmultind.txt Inductors of Various Inductances
indmultfreq.txt Inductors w/ Various Frequencies
impedance.txt Impedances of Same Magnitude
res-series.txt Series Resonance
res-par.txt Parallel Resonance
-
+Passive Filters
filt-hipass.txt High-Pass Filter (RC)
filt-lopass.txt Low-Pass Filter (RC)
filt-hipass-l.txt High-Pass Filter (RL)
filt-lopass-l.txt Low-Pass Filter (RL)
bandpass.txt Band-pass Filter
bandnoise.txt Band-pass w/ Noise
notch.txt Notch Filter
twint.txt Twin-T Filter
crossover.txt Crossover
butter10lo.txt Butterworth Low-Pass (10 pole)
butter10hi.txt Butterworth High-Pass (10 pole)
butter10loaud.txt Butterworth Low-Pass w/ Noise
butter10hiaud.txt Butterworth High-Pass w/ Noise
butterbandstop.txt Butterworth Band-Stop
besselbutter.txt Bessel vs Butterworth
ringing.txt Band-pass with Ringing
comb.txt Comb Filter
-
+Other Passive Circuits
+Series/Parallel
indseries.txt Inductors in Series
indpar.txt Inductors in Parallel
capseries.txt Caps in Series
cappar.txt Caps in Parallel
-
+Transformers
transformer.txt Transformer
transformerdc.txt Transformer w/ DC
transformerup.txt Step-Up Transformer
transformerdown.txt Step-Down Transformer
longdist.txt Long-Distance Power Transmission
-
+Relays
relay.txt Relay
relayand.txt Relay AND
relayor.txt Relay OR
relayxor.txt Relay XOR
relaymux.txt Relay Mux
relayff.txt Relay Flip-Flop
relaytff.txt Relay Toggle Flip-Flop
relayosc.txt Relay Oscillator
relayctr.txt Relay Counter
-
3way.txt 3-Way Light Switches
4way.txt 3- and 4-Way Light Switches
diff.txt Differentiator
wheatstone.txt Wheatstone Bridge
lrc-critical.txt Critically Damped LRC
currentsrcelm.txt Current Source
inductkick.txt Inductive Kickback
inductkick-snub.txt Blocking Inductive Kickback
powerfactor1.txt Power Factor
powerfactor2.txt Power Factor Correction
grid.txt Resistor Grid
grid2.txt Resistor Grid 2
cube.txt Resistor Cube
+Coupled LC's
coupled1.txt LC Modes (2)
coupled2.txt Weak Coupling
coupled3.txt LC Modes (3)
ladder.txt LC Ladder
-
phaseseq.txt Phase-Sequence Network
lissa.txt Lissajous Figures
-
+Diodes
diodevar.txt Diode
diodecurve.txt Diode I/V Curve
rectify.txt Half-Wave Rectifier
fullrect.txt Full-Wave Rectifier
fullrectf.txt Full-Wave Rectifier w/ Filter
diodelimit.txt Diode Limiter
+Zener Diodes
zeneriv.txt I/V Curve
zenerref.txt Voltage Reference
zenerreffollow.txt Voltage Reference w/ Follower
-
dcrestoration.txt DC Restoration
inductkick-block.txt Blocking Inductive Kickback
spikegen.txt Spike Generator
+Voltage Multipliers
voltdouble.txt Voltage Doubler
voltdouble2.txt Voltage Doubler 2
volttriple.txt Voltage Tripler
voltquad.txt Voltage Quadrupler
-
amdetect.txt AM Detector
diodeclip.txt Waveform Clipper
sinediode.txt Triangle-to-Sine Converter
ringmod.txt Ring Modulator
-
+Op-Amps
opamp.txt Op-Amp
opampfeedback.txt Op-Amp Feedback
+Amplifiers
amp-invert.txt Inverting Amplifier
amp-noninvert.txt Noninverting Amplifier
amp-follower.txt Follower
amp-diff.txt Differential Amplifier
amp-sum.txt Summing Amplifier
logconvert.txt Log Amplifier
classd.txt Class-D Amplifier
-
+Oscillators
relaxosc.txt Relaxation Oscillator
phaseshiftosc.txt Phase-Shift Oscillator
triangle.txt Triangle Wave Generator
sine.txt Sine Wave Generator
sawtooth.txt Sawtooth Wave Generator
vco.txt Voltage-Controlled Oscillator
trianglevco.txt Triangle VCO
-
amp-rect.txt Half-Wave Rectifier (inverting)
amp-fullrect.txt Full-Wave Rectifier
peak-detect.txt Peak Detector
amp-integ.txt Integrator
amp-dfdx.txt Differentiator (inverting)
amp-schmitt.txt Schmitt Trigger
nic-r.txt Negative Impedance Converter
gyrator.txt Gyrator
capmult.txt Capacitance Multiplier
howland.txt Howland Current Source
itov.txt I-to-V Converter
delta-pwm.txt Delta PWM Encoder
opamp-regulator.txt Voltage Regulator
opint.txt 741 Internals
opint-invert-amp.txt 741 (inverting amplifier)
opint-slew.txt 741 Slew Rate
opint-current.txt 741 Current Limits
+Chaotic Circuits
rossler.txt Rossler
vilnius.txt Vilnius
chua.txt Chua
chaos1.txt Chaos 1
chaos2.txt Chaos 2
jerk.txt Jerk
-
-
+Transistors
npn.txt NPN Transistor
pnp.txt PNP Transistor
transswitch.txt Switch
follower.txt Emitter Follower
+Multivibrators
multivib-a.txt Astable Multivib
multivib-bi.txt Bistable Multivib (Flip-Flop)
multivib-mono.txt Monostable Multivib (One-Shot)
-
ceamp.txt Common-Emitter Amplifier
phasesplit.txt Unity-Gain Phase Splitter
schmitt.txt Schmitt Trigger
currentsrc.txt Current Source
currentsrcramp.txt Current Source Ramp
mirror.txt Current Mirror
darlington.txt Darlington Pair
+Differential Amplifiers
trans-diffamp.txt Differential Input
trans-diffamp-common.txt Common-Mode Input
trans-diffamp-cursrc.txt Common-Mode w/Current Source
-
+Push-Pull Follower
pushpullxover.txt Simple, with distortion
pushpull.txt Improved
-
+Oscillators
colpitts.txt Colpitts Oscillator
hartley.txt Hartley Oscillator
eclosc.txt Emitter-Coupled LC Oscillator
crystalosc2.txt Crystal Oscillator
-
gilbertcell.txt Gilbert Cell Multiplier
rmsconverter.txt True RMS Converter
joule-thief.txt Joule Thief
transrectifier.txt Full-Wave Rectifier
-
+MOSFETs
nmosfet.txt n-MOSFET
pmosfet.txt p-MOSFET
mosswitch.txt Switch
mosfollower.txt Source Follower
moscurrentsrc.txt Current Source
moscurrentramp.txt Current Ramp
mosmirror.txt Current Mirror
mosfetamp.txt Common-Source Amplifier
cmosinverter.txt CMOS Inverter
cmosinvertercap.txt CMOS Inverter (w/capacitance)
cmosinverterslow.txt CMOS Inverter (slow transition)
cmostransgate.txt CMOS Transmission Gate
mux.txt CMOS Multiplexer
samplenhold.txt Sample-and-Hold
delayrc.txt Delayed Buffer
leadingedge.txt Leading-Edge Detector
switchfilter.txt Switchable Filter
voltinvert.txt Voltage Inverter
invertamp.txt Inverter Amplifier
inv-osc.txt Inverter Oscillator
analogrecip.txt Analog Reciprocal
crystalosc.txt CMOS Crystal Oscillator
-
+555 Timer Chip
555square.txt Square Wave Generator
555int.txt Internals
555saw.txt Sawtooth Oscillator
555lowduty.txt Low-duty-cycle Oscillator
555monostable.txt Monostable Multivibrator
555pulsemod.txt Pulse Width Modulator
555sequencer.txt Pulse Sequencer
555schmitt.txt Schmitt Trigger (inverting)
555missing.txt Missing Pulse Detector
-
+Active Filters
filt-vcvs-lopass.txt VCVS Low-Pass Filter
filt-vcvs-hipass.txt VCVS High-Pass Filter
switchedcap.txt Switched-Capacitor Filter
allpass1.txt Allpass
allpass2.txt Allpass w/ Square
actbutterlo.txt Butterworth Low-Pass
actbutterhi.txt Butterworth High-Pass
actbutterband.txt Butterworth Band-Pass
-
+Logic Families
+RTL
rtlinverter.txt RTL Inverter
rtlnor.txt RTL NOR
rtlnand.txt RTL NAND
-
+DTL
dtlinverter.txt DTL Inverter
dtlnand.txt DTL NAND
dtlnor.txt DTL NOR
-
+TTL
ttlinverter.txt TTL Inverter
ttlnand.txt TTL NAND
ttlnor.txt TTL NOR
fanout.txt Fan-Out
-
+NMOS
nmosinverter.txt NMOS Inverter
nmosinverter2.txt Inverter with only MOSFETs
nmosinverter3.txt Depletion-load NMOS Inverter
nmosnand.txt NMOS NAND
-
+CMOS
cmosinverter.txt CMOS Inverter
cmosnand.txt CMOS NAND
cmosnor.txt CMOS NOR
cmosxor.txt CMOS XOR
cmosff.txt CMOS Flip-Flop
cmosmsff.txt CMOS Master-Slave Flip-Flop
-
+ECL
eclnor.txt ECL NOR/OR
-
+Ternary
3-cgand.txt CGAND
3-cgor.txt CGOR
3-invert.txt Complement (F210)
3-f211.txt F211
3-f220.txt F220
3-f221.txt F221
-
-
+Combinational Logic
xor.txt Exclusive OR
halfadd.txt Half Adder
fulladd.txt Full Adder
decoder.txt 1-of-4 Decoder
priencoder.txt Priority Encoder
mux3state.txt 2-to-1 Mux
majority.txt Majority Logic
digcompare.txt 2-Bit Comparator
7segdecoder.txt 7-Segment LED Decoder
brentkung.txt Brent-Kung Adder
alu74181.txt 74181 ALU
-
+Sequential Logic
+Flip-Flops
nandff.txt SR Flip-Flop
clockedsrff.txt Clocked SR Flip-Flop
masterslaveff.txt Master-Slave Flip-Flop
edgedff.txt Edge-Triggered D Flip-Flop
jkff.txt JK Flip-Flop
-
+Counters
counter.txt 4-Bit Ripple Counter
counter8.txt 8-Bit Ripple Counter
synccounter.txt Synchronous Counter
updownctr.txt Up/Down Counter
deccounter.txt Decimal Counter
graycode.txt Gray Code Counter
johnsonctr.txt Johnson Counter
ringcascade.txt Cascading Ring Counters
-
+Shift Registers
sipo-sr.txt Serial-In Parallel-Out
piso-sr.txt Parallel-In Serial-Out
unishiftreg.txt Universal
-
divideby2.txt Divide-by-2
divideby3.txt Divide-by-3
ledflasher.txt LED Flasher
traffic.txt Traffic Light
sram.txt Static RAM
dram.txt Dynamic RAM
-
+Analog/Digital
flashadc.txt Flash ADC
deltasigma.txt Delta-Sigma ADC
hfadc.txt Half-Flash (Subranging) ADC
dac.txt Binary-Weighted DAC
r2rladder.txt R-2R Ladder DAC
swtreedac.txt Switch-Tree DAC
digsine.txt Digital Sine Wave
qam-256.txt QAM-256 Modulator/Demodulator
-
+Power Converters
conv-boost.txt Boost Converter
conv-buck.txt Buck Converter
conv-buckboost.txt Buck-Boost Converter
conv-cuk.txt Ćuk Converter
conv-sepic.txt SEPIC Converter
-
+Phase-Locked Loops
xorphasedet.txt XOR Phase Detector
pll.txt Type I PLL
phasecomp.txt Phase Comparator (Type II)
phasecompint.txt Phase Comparator Internals
pll2.txt Type II PLL
pll2a.txt Type II PLL (fast)
freqdouble.txt Frequency Doubler
-
+Transmission Lines
tl.txt Simple TL
tlstand.txt Standing Wave
tlterm.txt Termination
tlmismatch.txt Mismatched lines (Pulse)
tlmis1.txt Mismatched lines (Standing Wave)
tlmatch1.txt Impedance Matching (L-Section)
tlmatch2.txt Impedance Matching (Shunt Stub)
tlfreq.txt Stub Frequency Response
tllopass.txt Low-Pass Filter
tllight.txt Light Switch
-
+Misc Devices
+JFETs
jfetcurrentsrc.txt JFET Current Source
jfetfollower.txt JFET Follower
jfetfollower-nooff.txt JFET Follower w/zero offset
jfetamp.txt Common-Source Amplifier
volume.txt Volume Control
lambda-diode.txt Lambda Diode
lambda-diode-osc.txt Lambda Diode Oscillator
-
+Tunnel Diodes
tdiode.txt I/V Curve
tdosc.txt LC Oscillator
tdrelax.txt Relaxation Oscillator
-
+Memristors
mr.txt Memristor
mr-sine.txt Sine Wave
mr-square.txt Square Wave
mr-triangle.txt Triangle Wave
mr-sine2.txt Hard-Switching 1
mr-sine3.txt Hard-Switching 2
mr-crossbar.txt Crossbar Memory
-
+Triodes
triode.txt Triode
triodeamp.txt Amplifier
-
+Silicon-Controlled Rectifiers
scr.txt SCR
scractrig.txt AC Trigger
-
+Current Conveyor
cc2.txt CCII+
cc2n.txt CCII-
ccinductor.txt Inductor Simulator
cc2imp.txt CCII+ Implementation
cc2impn.txt CCII- Implementation
cciamp.txt Current Amplifier
ccvccs.txt VCCS
ccdiff.txt Current Differentiator
ccint.txt Current Integrator
ccitov.txt Current-Controlled Voltage Source
-
+Spark Gap
spark-sawtooth.txt Sawtooth Generator
tesla.txt Tesla Coil
spark-marx.txt Marx Generator
-
+Operational Transconductance Amplifier (OTA)
ota-vca.txt OTA Voltage Controlled Amplifier (VCA)
ota-vcf-single.txt OTA Single Stage VCF (low pass)
ota-ringmod.txt OTA Ring Modulator
ota-gain.txt LM137000 Gain Oddity
-
+Light Bulb
lightbulb.txt Light Bulb
wienbridge.txt Wien Bridge Oscillator
-
+Varactor
varactor.txt Varactor
varactorvco.txt VCO
-
ledarray.txt LED Array
triacdimmer.txt DIAC/TRIAC Dimmer
ujtosc.txt Unijunction Oscillator
-
blank.txt Blank Circuit

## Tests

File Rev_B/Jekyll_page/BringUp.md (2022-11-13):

---
layout: default
title: BringUp
nav_order: 5
parent: Rev B0
---

# BringUp

Okay, after some debugging, the board could work through all of its stages. Moreover, after I closely looked at the voltage on an oscilloscope, they looked cleaner than I expected, except for the Voltage protection stage. There may be some backpropagation from Vboost, but that should not be an issue. However, one should revisit simulations to see if that is expected.

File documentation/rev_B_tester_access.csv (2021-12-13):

pcie connector used for testing porpuses
pin | side | description | use on this project
1 | b | 12 V power | VIN
2 | b | 12 V power | VIN
3 | b | 12 V power | VIN
4 | b | Ground | ground
5 | b | smclk | i2c
6 | b | smdat | i2c
7 | b | Ground | ground
8 | b | 3.3 V power | VOUT
9 | b | trst# | test point voltage
10 | b | 3.3 V power | VOUT
11 | b | WAKE | chip select
 |  | key notch
12 | b | clkreg# | NA
13 | b | Ground | ground
14 | b | hsop | NA
15 | b | hson | NA
16 | b | Ground | ground
17 | b | prsnt | preset
18 | b | Ground | ground
 |  | pciex1 end
1 | a | prsnt | present
2 | a | 12 V power | VIN
3 | a | 12 V power | VIN
4 | a | Ground | ground
5 | a | tck | test point voltage
6 | a | tdi | test point voltage
7 | a | tdo | test point voltage
8 | a | tms | test point voltage
9 | a | 3.3 V power | VOUT
10 | a | 3.3 V power | VOUT
11 | a | perst | Reset / disable
 |  | key notch
12 | a | Ground | ground
13 | a | refclk | sense line for vout
14 | a | refclk | sense line for vout
15 | a | Ground | ground
16 | a | hsip | NA
17 | a | hsin | NA
18 | a | Ground | ground

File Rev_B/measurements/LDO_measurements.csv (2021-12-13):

test | Vset [V] | Vcharged [V] | Vin [V] | Iin [A] | Vout [V] | Iout [A] | Vin – Vout [V] | “Burned” power [W]
10mA test | 5.000 | 18.727 | 7.028 | 0.014 | 5.017 | 0.013 | 2.011 | 0.026
10mA test | 5.000 | 15.729 | 6.028 | 0.013 | 5.018 | 0.013 | 1.010 | 0.013
10mA test | 5.000 | 12.705 | 5.027 | 0.013 | 5.019 | 0.013 | 0.008 | 0.000
100mA test | 5.000 | 18.630 | 7.028 | 0.104 | 5.013 | 0.102 | 2.015 | 0.206
100mA test | 5.000 | 15.617 | 6.028 | 0.104 | 5.013 | 0.102 | 1.015 | 0.104
100mA test | 5.000 | 12.699 | 5.027 | 0.102 | 4.995 | 0.102 | 0.032 | 0.003
1A test | 5.000 | 19.230 | 7.027 | 1.018 | 4.952 | 1.012 | 2.075 | 2.100
1A test | 5.000 | 15.530 | 6.027 | 1.016 | 4.957 | 1.013 | 1.070 | 1.084
1A test | 5.000 | 12.477 | 5.027 | 1.013 | 4.627 | 1.013 | 0.400 | 0.405
2A test | 5.000 | 18.588 | 7.027 | 2.010 | 4.890 | 2.012 | 2.137 | 4.300
2A test | 5.000 | 15.178 | 6.028 | 2.014 | 4.890 | 2.012 | 1.138 | 2.290
2A test | 5.000 | 12.235 | 5.027 | 2.013 | 4.212 | 2.012 | 0.815 | 1.640
min Vdiff | 5.000 | 13.887 | 5.500 | 1.014 | 4.954 | 1.013 | 0.546 | 0.553
min Vdiff | 5.000 | 13.591 | 5.400 | 1.014 | 4.954 | 1.013 | 0.446 | 0.452
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

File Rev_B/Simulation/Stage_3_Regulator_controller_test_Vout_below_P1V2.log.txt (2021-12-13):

vfb_ref	vout1
0.000000000000000e+000	2.594270e+000
2.100000000000000e-002	2.573360e+000
4.200000000000000e-002	2.552450e+000
6.300000000000000e-002	2.531540e+000
8.400000000000001e-002	2.510640e+000
1.050000000000000e-001	2.489730e+000
1.260000000000000e-001	2.468820e+000
1.470000000000000e-001	2.447910e+000
1.680000000000000e-001	2.427010e+000
1.890000000000000e-001	2.406100e+000
2.100000000000000e-001	2.385180e+000
2.310000000000000e-001	2.364280e+000
2.520000000000000e-001	2.343360e+000
2.730000000000000e-001	2.322460e+000
2.940000000000000e-001	2.301550e+000
3.150000000000000e-001	2.280630e+000
3.360000000000000e-001	2.259720e+000
3.570000000000000e-001	2.238810e+000
3.780000000000000e-001	2.217900e+000
3.990000000000000e-001	2.196990e+000
4.200000000000000e-001	2.176080e+000
4.410000000000000e-001	2.155170e+000
4.620000000000000e-001	2.134250e+000
4.830000000000000e-001	2.113340e+000
5.040000000000000e-001	2.092420e+000
5.250000000000000e-001	2.071510e+000
5.460000000000000e-001	2.050590e+000
5.670000000000000e-001	2.029680e+000
5.880000000000000e-001	2.008760e+000
6.090000000000000e-001	1.987850e+000
6.300000000000000e-001	1.966930e+000
6.510000000000000e-001	1.946020e+000
6.720000000000000e-001	1.925100e+000
6.930000000000000e-001	1.904180e+000
7.140000000000000e-001	1.883260e+000
7.350000000000000e-001	1.862340e+000
7.560000000000000e-001	1.841430e+000
7.770000000000000e-001	1.820510e+000
7.980000000000000e-001	1.799590e+000
8.190000000000000e-001	1.778670e+000
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

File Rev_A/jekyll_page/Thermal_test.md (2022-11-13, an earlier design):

---
title: Thermal_test
has_children: no
nav_order: 6
parent: Rev A0
---
This was an initial thermal test outputing ~1 Watt. 

## Thermal test
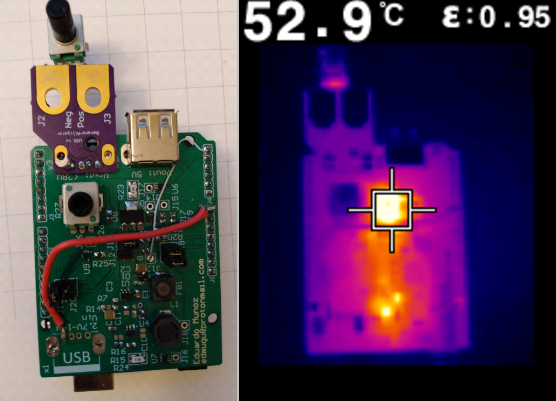
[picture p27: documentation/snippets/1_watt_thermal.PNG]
thermal picture Thermal picture


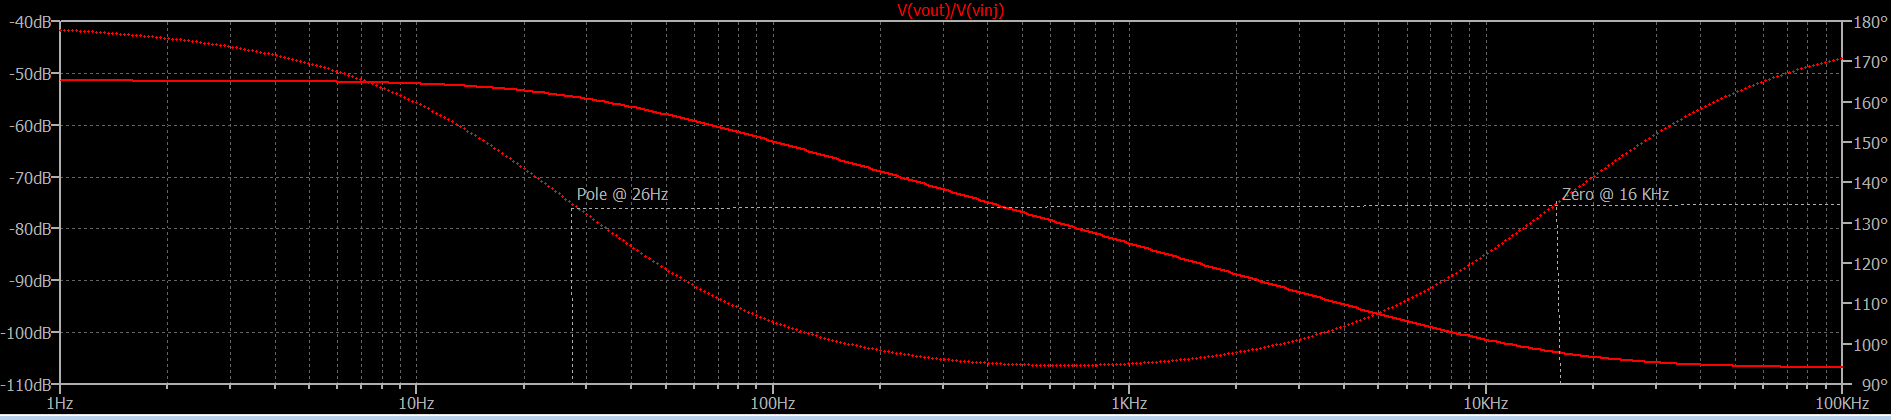
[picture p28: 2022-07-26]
Rev_B/Jekyll_page/snipits/Stage_1_Boost_controller_test_inj_trasformer.PNG

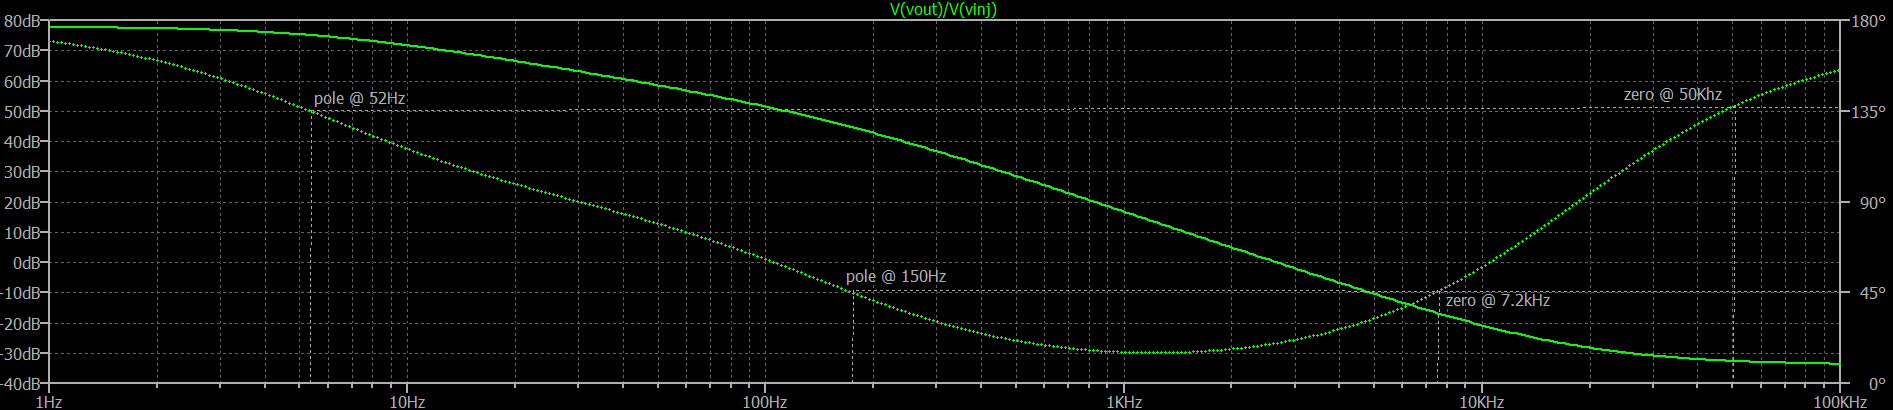
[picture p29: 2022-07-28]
Rev_B/Jekyll_page/snipits/Stage_3_Regulator_controller_test_inj_trasformer.PNG

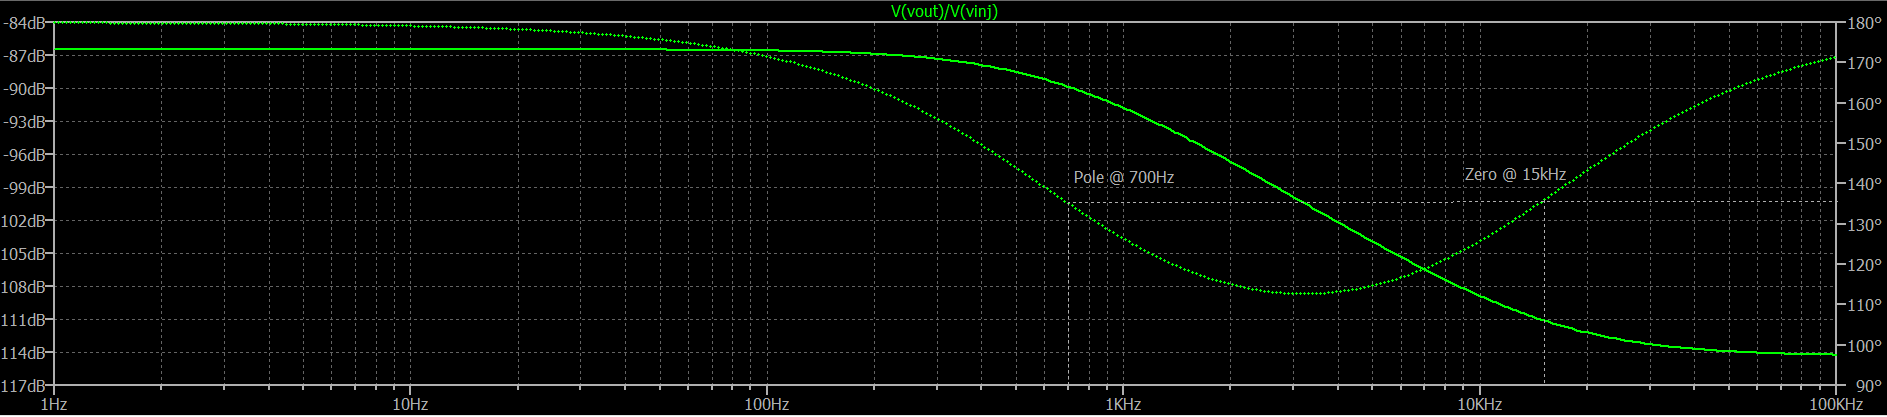
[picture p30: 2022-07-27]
Rev_B/Jekyll_page/snipits/Stage_2_Boost_controller_test_inj_trasformer.PNG

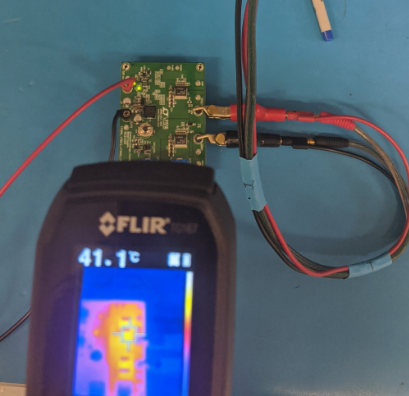
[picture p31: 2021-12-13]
documentation/snippets/analog_board_temp_test_1.PNG

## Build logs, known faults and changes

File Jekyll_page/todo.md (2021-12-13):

---
title: Todo
has_children: no
nav_order: 50
parent:Rev. A
---

* Before Next Hardware revision
  * check the firmata's i2c support on https://mryslab.github.io/pymata4/ 

* Must have fixes on the Next Hardware revision
  * Fix the Diode footprint that is backwards
    * Add a jumper to connect the board vin to the Arduino Vin 
  * Add LED lights to indicate 
    * That the voltage levels are good
    * That there is no over-current event
  * Make the module stack-able
    * Add i2c ADC to free the Arduino ADC
    * Add i2c repeater like PCA9515A to control the i2c bus between modules
      * Add i2c eeprom to save some calibration values
        * Replace some capacitor SMA to BIG through hole capacitors 

* Nice to have fixes on the Next Hardware revision
  * Better banana connectors on the output
  * silk layer with more expiation on each stage of the module

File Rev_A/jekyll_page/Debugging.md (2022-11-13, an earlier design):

---
title: Debugging
has_children: no
nav_order: 2
parent: Rev A0
---

# Debugging Process
## Bug 1: The voltage of the first stage does not go above Vin
After checking that the enable pin was high and that the switching output was doing what it was supposed to be doing, I decided to replace the IC. However, it still showed the same behavior. First, Vout would reach >30 Volts; then it would drop to Vin. Then I checked my IC units on an eval board, and they work. At that moment, I started to investigate the second most complicated unit on the first stage, the diode. Then it was clear that the issue was that I installed the diode backward. However, the silkscreen and schematics had the diode in the right orientation. So that meant the footprint pads of the diode were swapped.

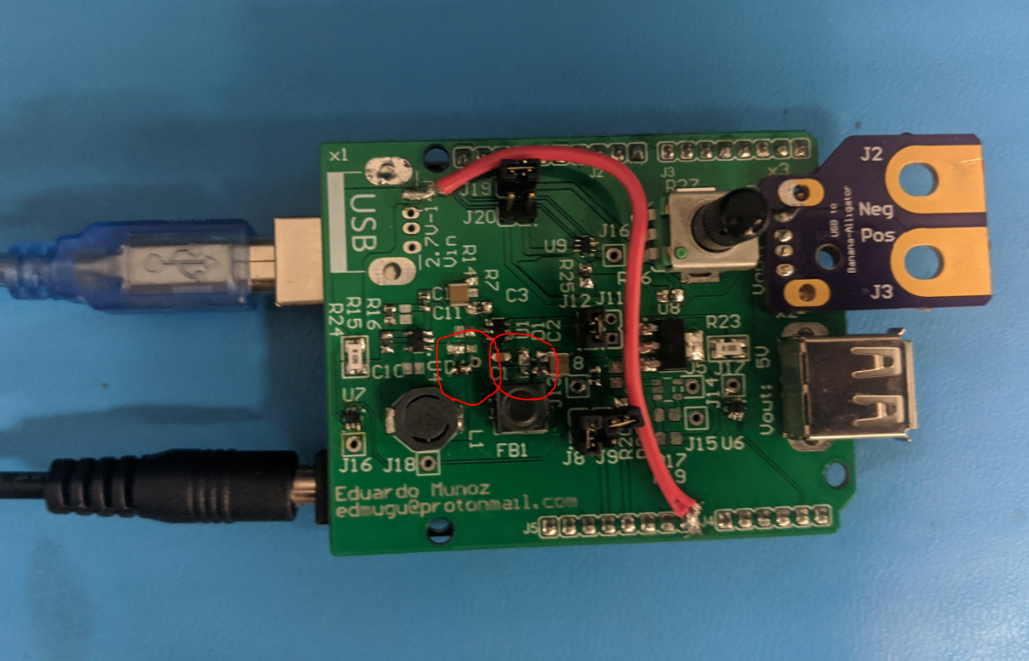
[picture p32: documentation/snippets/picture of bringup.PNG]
board bring up


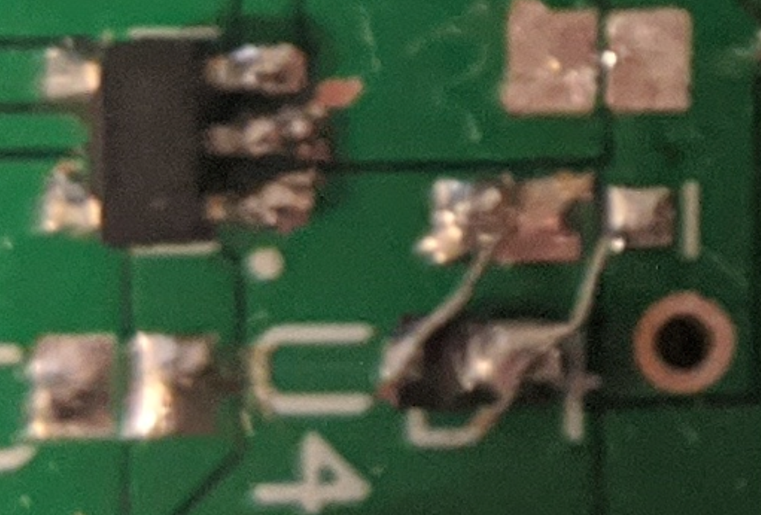
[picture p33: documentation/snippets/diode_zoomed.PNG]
diode zoomed


## Bug 2: The output of the final stage was stuck at 1.8 Volts
Note that the feedback to the last two stages can be selected between a "fixed" voltage divided that would allow the output to go all the way to 27 volts. Or it can be selected to be the dynamic feedback circuit that would keep the voltage of the last two stages close to each other. The circuit worked fine when a fixed voltage divider was used; however, it got stuck at 1.8 volts when it was switch to the dynamic feedback. At that moment, the feedback circuit was set to have a 0.8 Volts difference between the two stages. And indeed, there was a 0.8-volt difference between the stages. So I thought that maybe if I raised the difference to 5 volts, it would work. Luckily, it did, and after looking for an explanation, I noted that the linear regulator needed at least a 3 volts difference between its output and its input. 
	
## Bug 3: The output can only drive <1 mA before it starts to struggle. 
I believed this is due to the SMD capacitors. However, I noted that this issue went away if I lowered the voltage to the minimum voltage of 1.2V and then raised it to the wanted voltage. So it seems that the step-down switch and regulator had issues if the initial load was too much. So I decided to make a prototype out of evaluation boards to check this behavior because my board already had a compromising rework on the Schottky diodes. When I characterized the prototype, it was only able to output 5 Watts when the design should have had been able to handle >10 Watts. 

A few notes on the prototype: 
	(1) the evaluation board of the step-down circuit is for the LMR14006 component, but it has the same pinout as the AOZ1282. So the unit was swapped.
	(2) the wires used are size AWG 20, and they can handle 1.5 amps; this should not be a limiting factor yet.
	
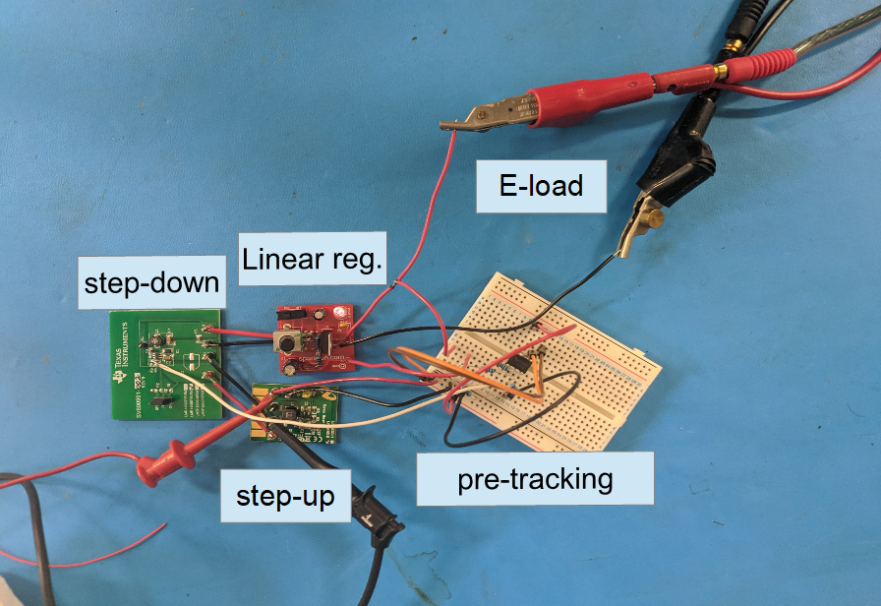
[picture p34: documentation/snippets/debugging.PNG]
prototype out of eval boards


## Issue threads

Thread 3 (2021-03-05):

Tester access

edmugu, 2021-03-05:
In order to test a batch of power supplies it should be good to have an easy connector that allows access to a tester board.

One option is to have a PCIe connector that gives access to all the stages of the power supply

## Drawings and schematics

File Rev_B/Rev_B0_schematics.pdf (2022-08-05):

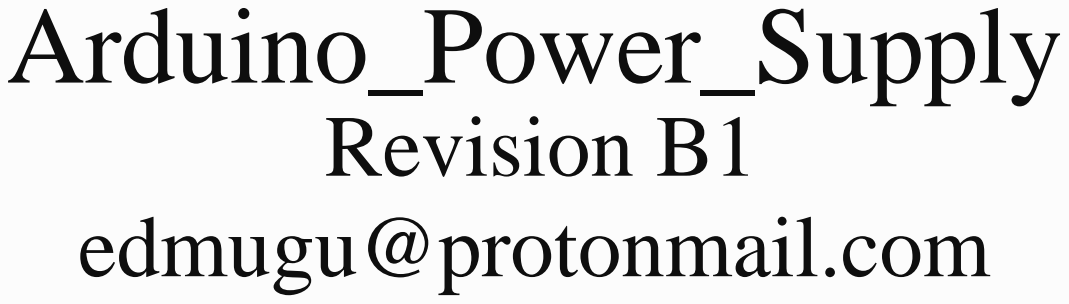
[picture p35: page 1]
Date:; Sheet of; File:; Title.SchDoc; Drawn By:; Revision B1

edmugu@protonmail.com

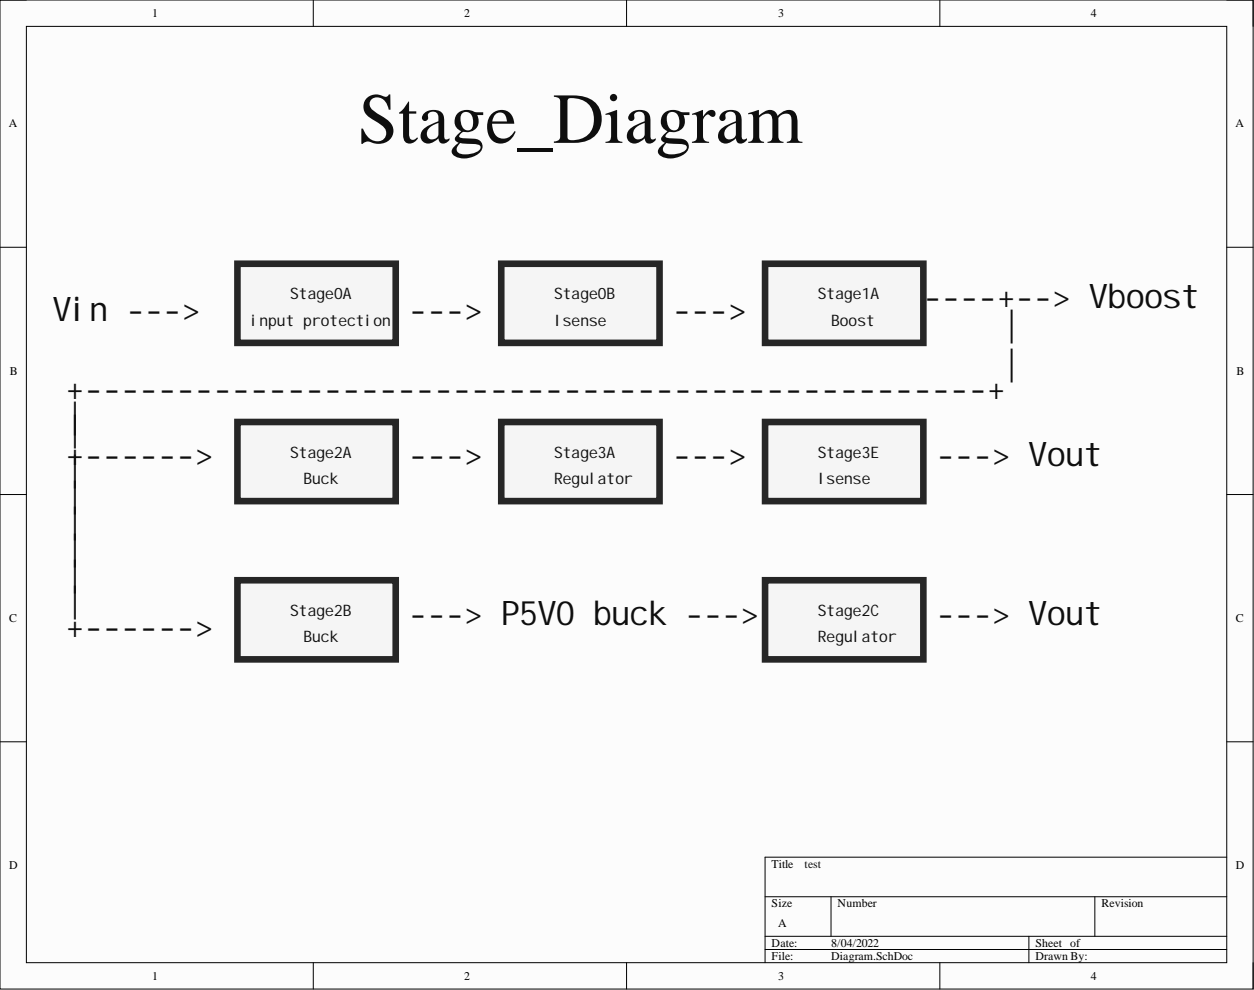
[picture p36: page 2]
File:; Diagram.SchDoc; Drawn By:; input protection; Vin --->; ---> Vout; ---> P5V0 buck --->; ----+--> Vboost

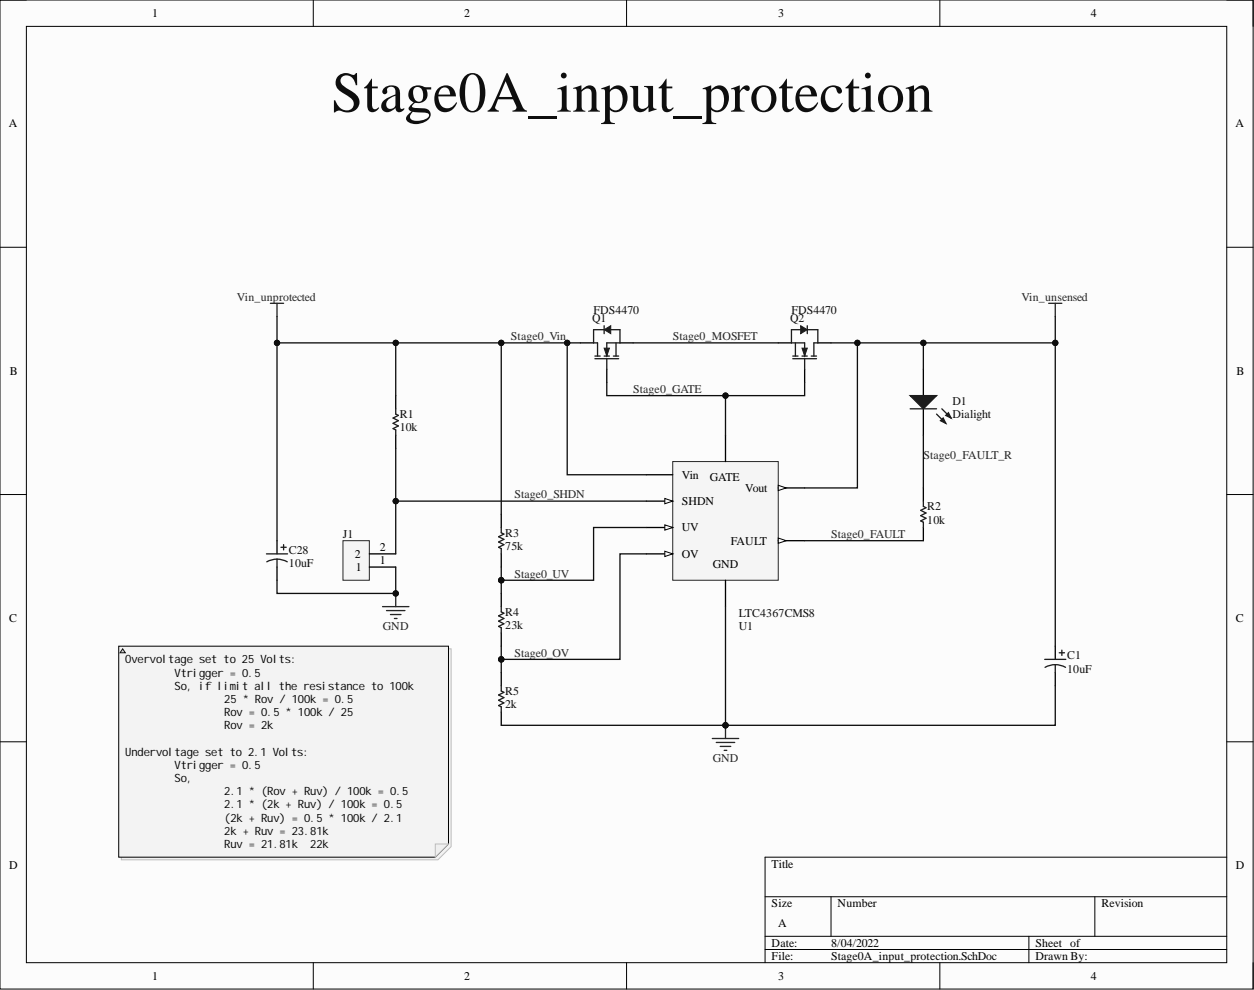
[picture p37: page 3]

1 | Stage0 _U V

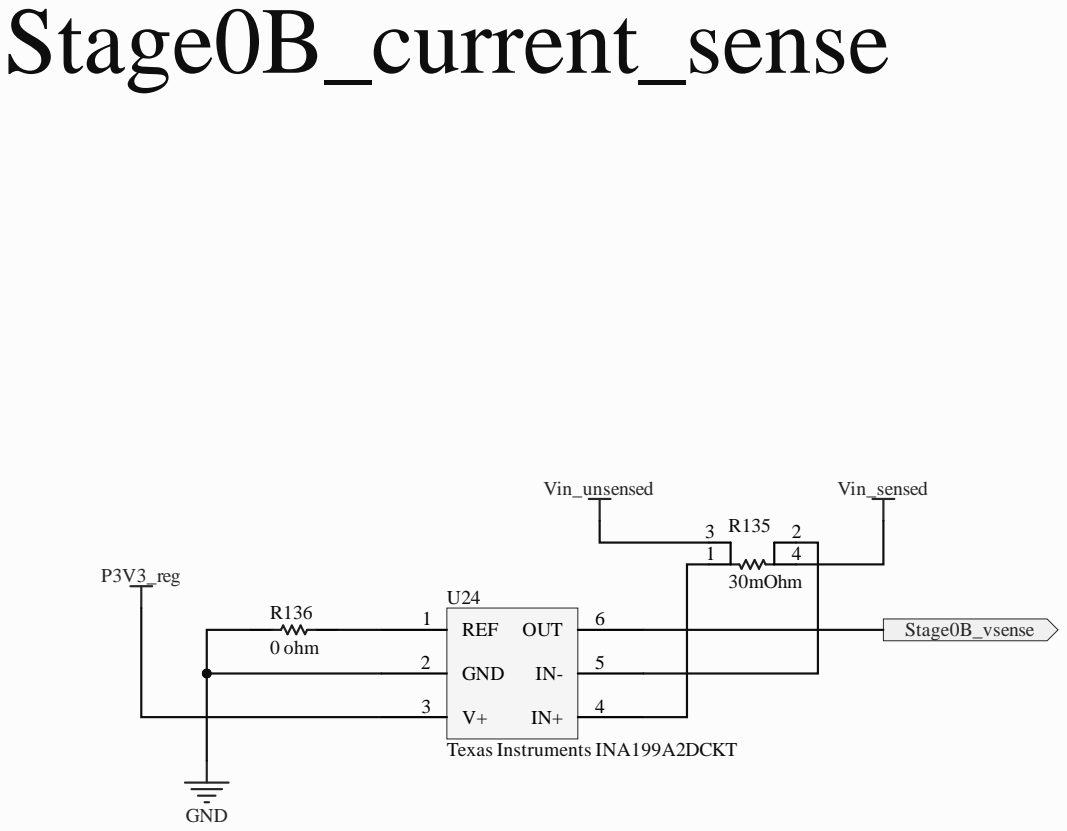
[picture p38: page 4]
File:; Stage0B_current_sense.SchDoc; Drawn By:; REF 1; GND 2; Texas Instruments INA199A2DCKT; 0 ohm

Q4 Stage1_SENSE_R

Stage1_GATE

Stage1_SYNC | | | Stage1_RT

Stage1_SS | SS 3 | | Stage1_VC

FB voltage set to 38 volts:

But to control the voltage the Vfb comes
from an average between FB resistors and
PWM from arduino.

Note that if FB is held above 1.7
Vout will drop down to Vin [NOT 0!]

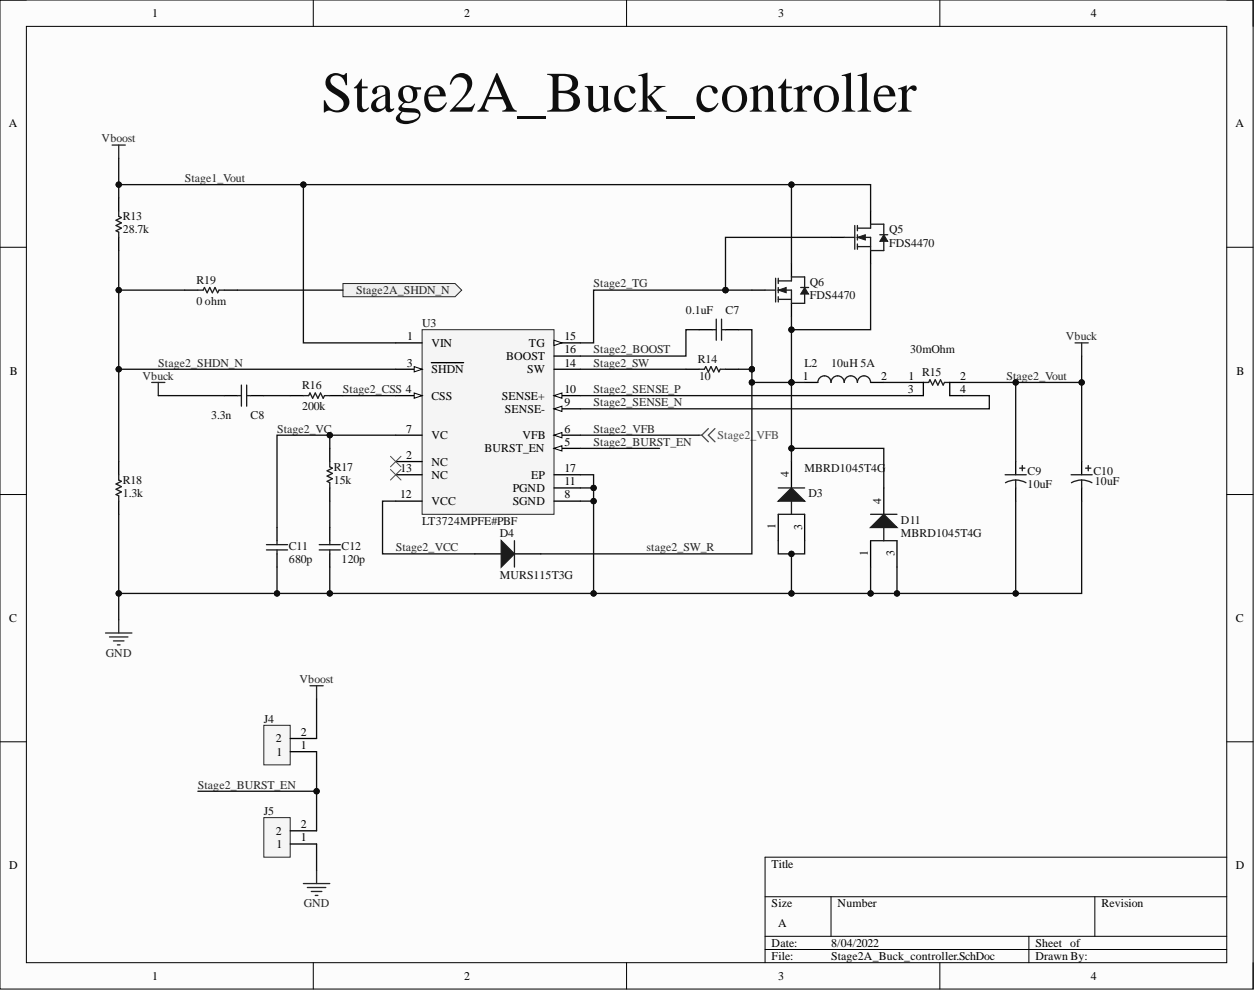
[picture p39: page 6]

Stage2_SHDN_N | | Stage2_TG

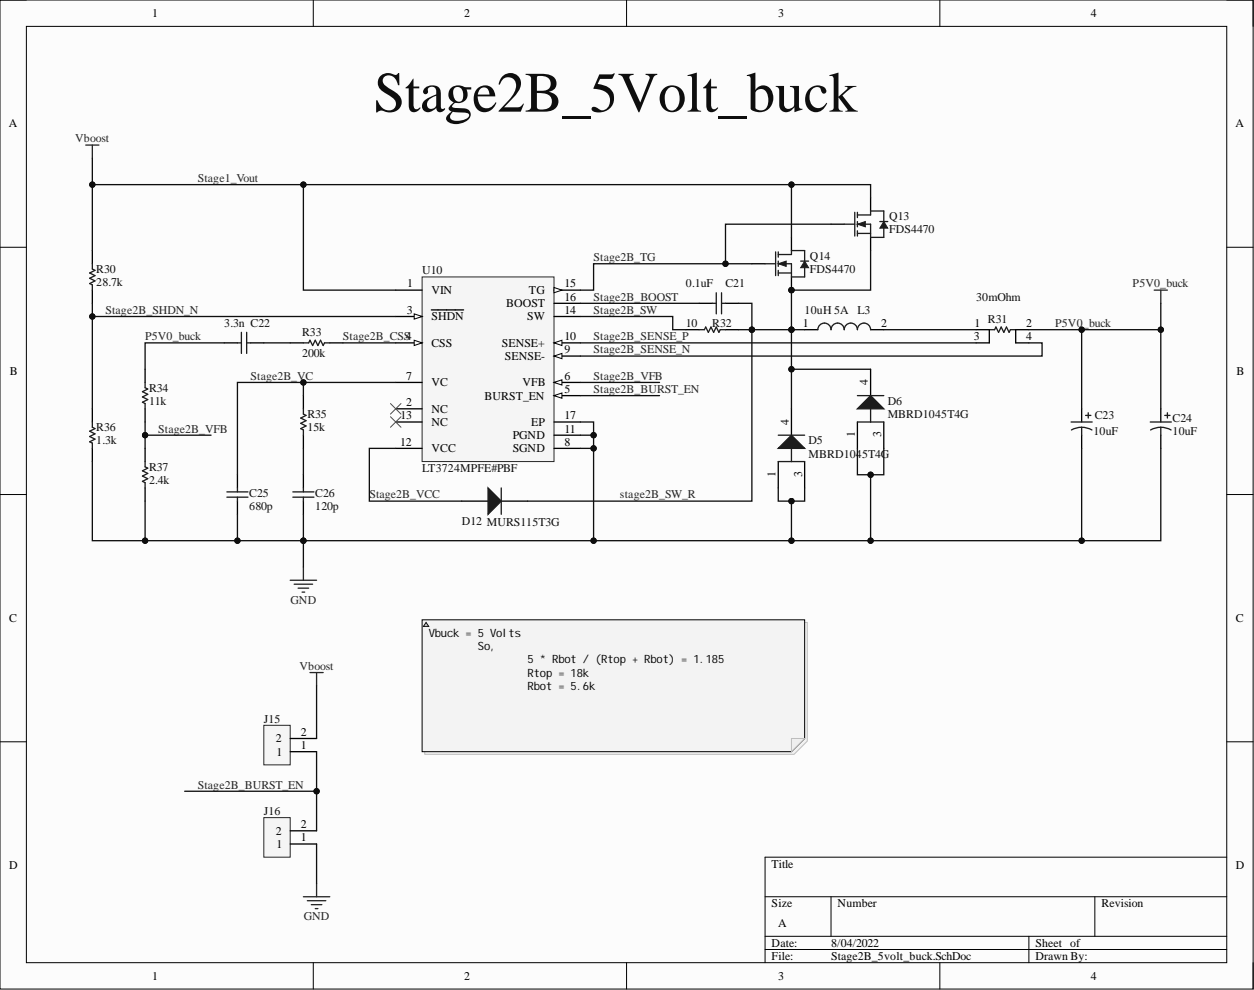
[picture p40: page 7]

3.3n C22 | | CSS 4

stage2B_SW_R

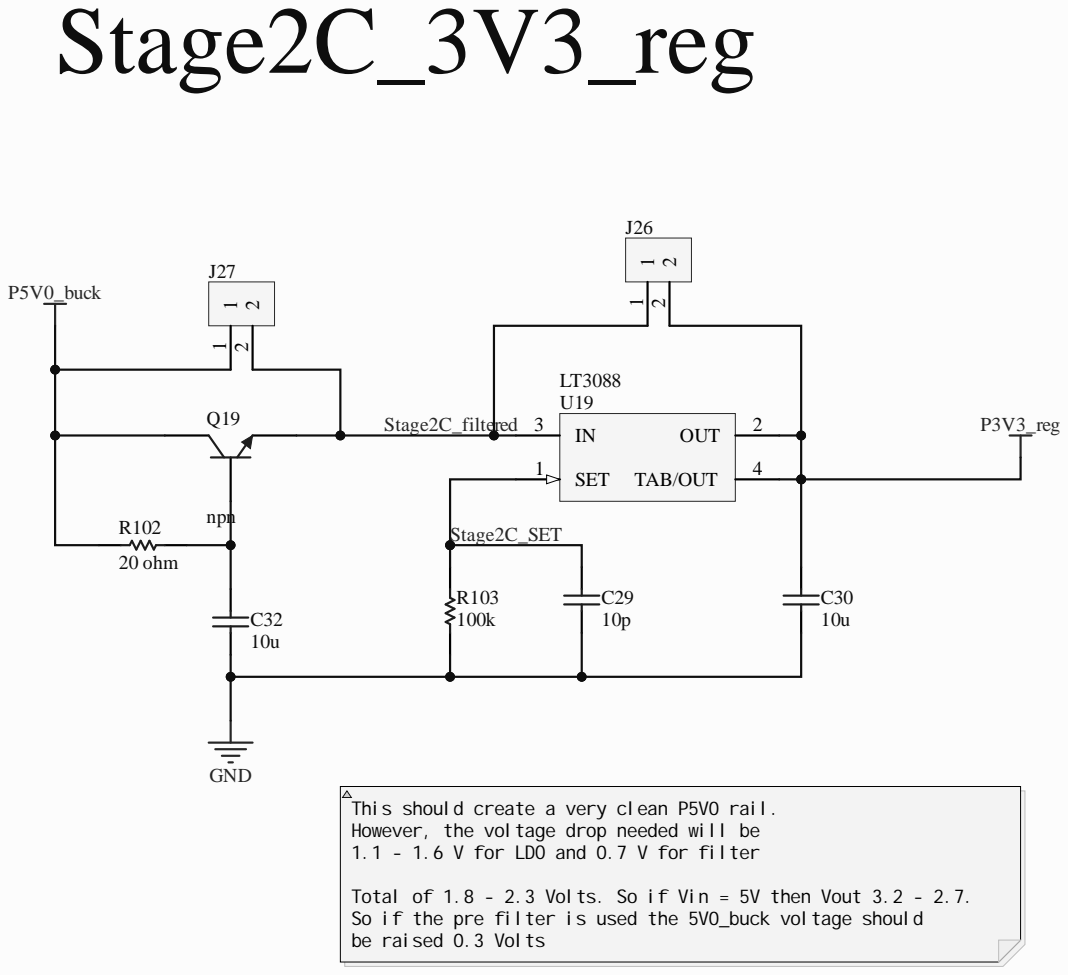
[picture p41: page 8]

This should create a very clean P5V0 rail.
However, the voltage drop needed will be
1.1 - 1.6 V for LDO and 0.7 V for filter

Total of 1.8 - 2.3 Volts. So if Vin = 5V then Vout 3.2 - 2.7.
So if the pre filter is used the 5V0_buck voltage should
be raised 0.3 Volts

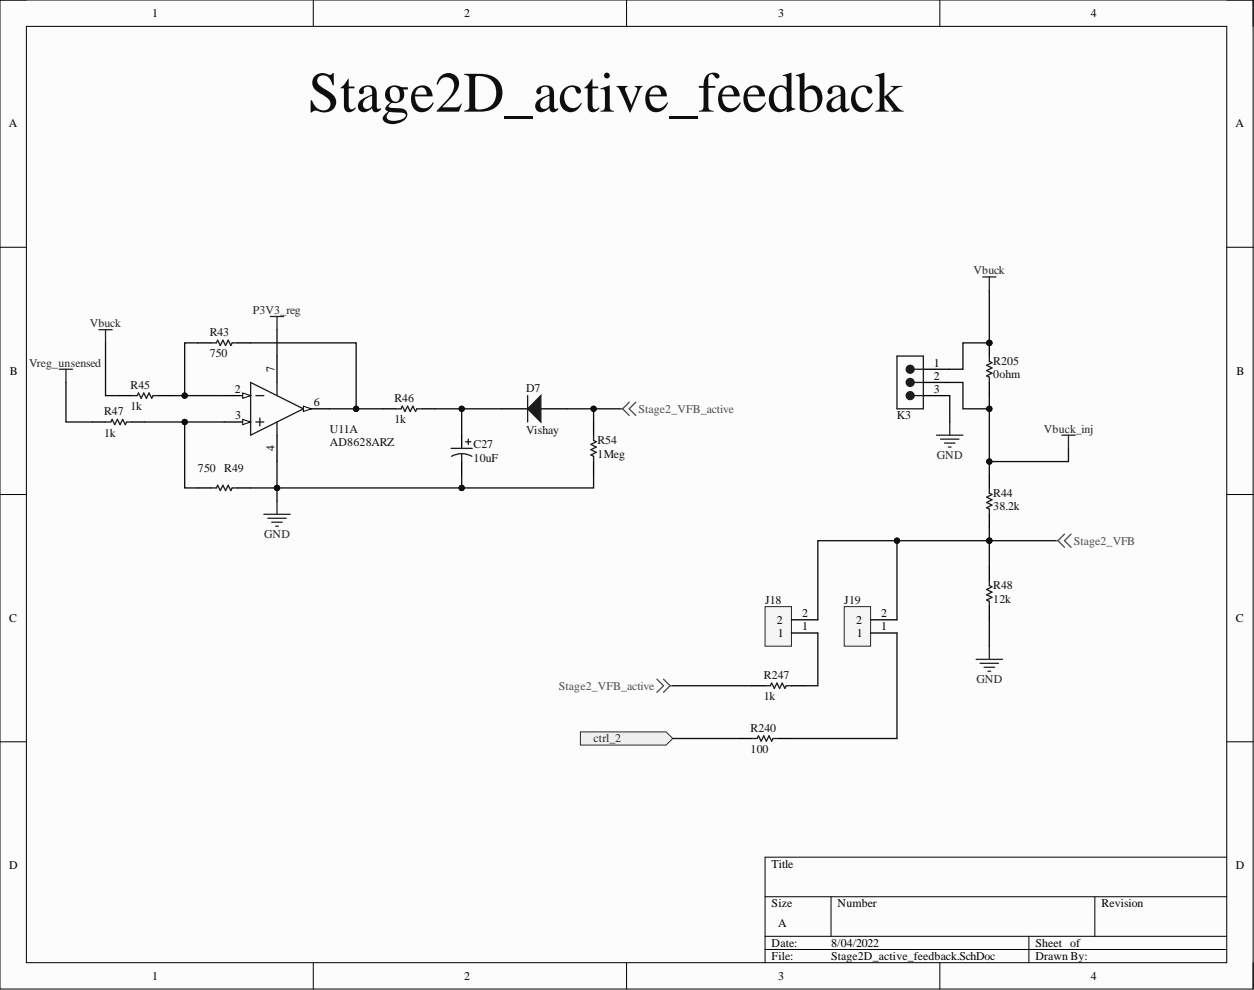
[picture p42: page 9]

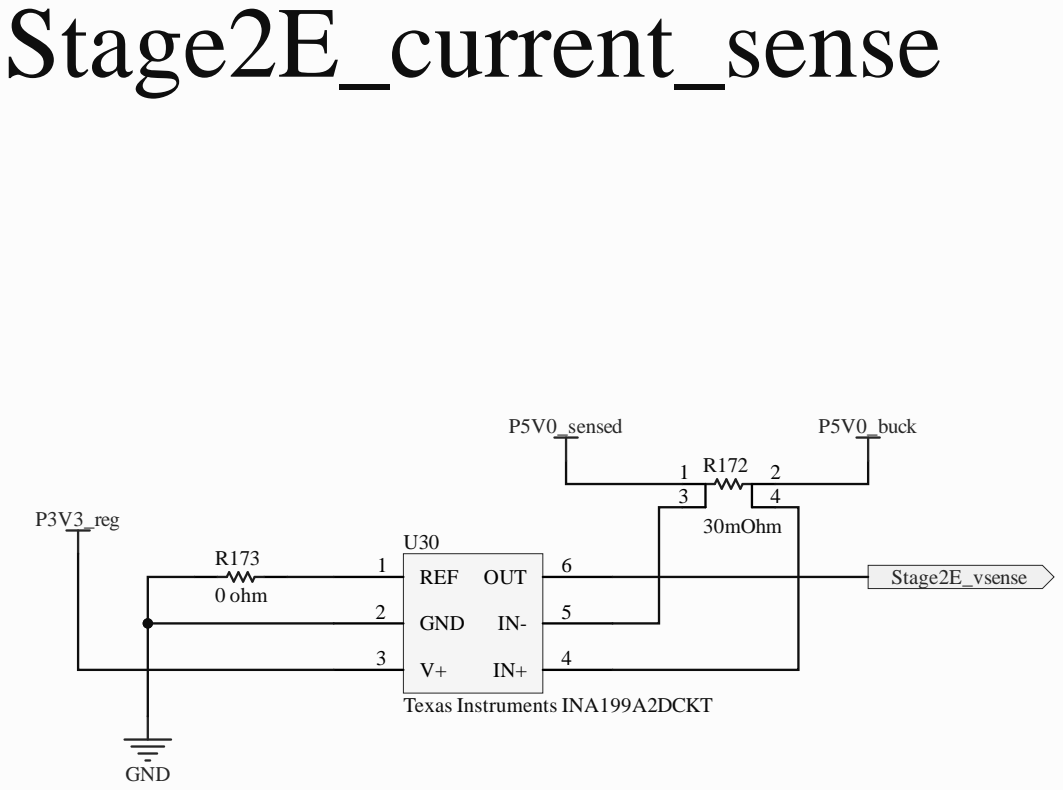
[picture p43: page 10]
File:; Steage2E_current_sense.SchDoc; Drawn By:; REF 1; GND 2; Texas Instruments INA199A2DCKT; 0 ohm

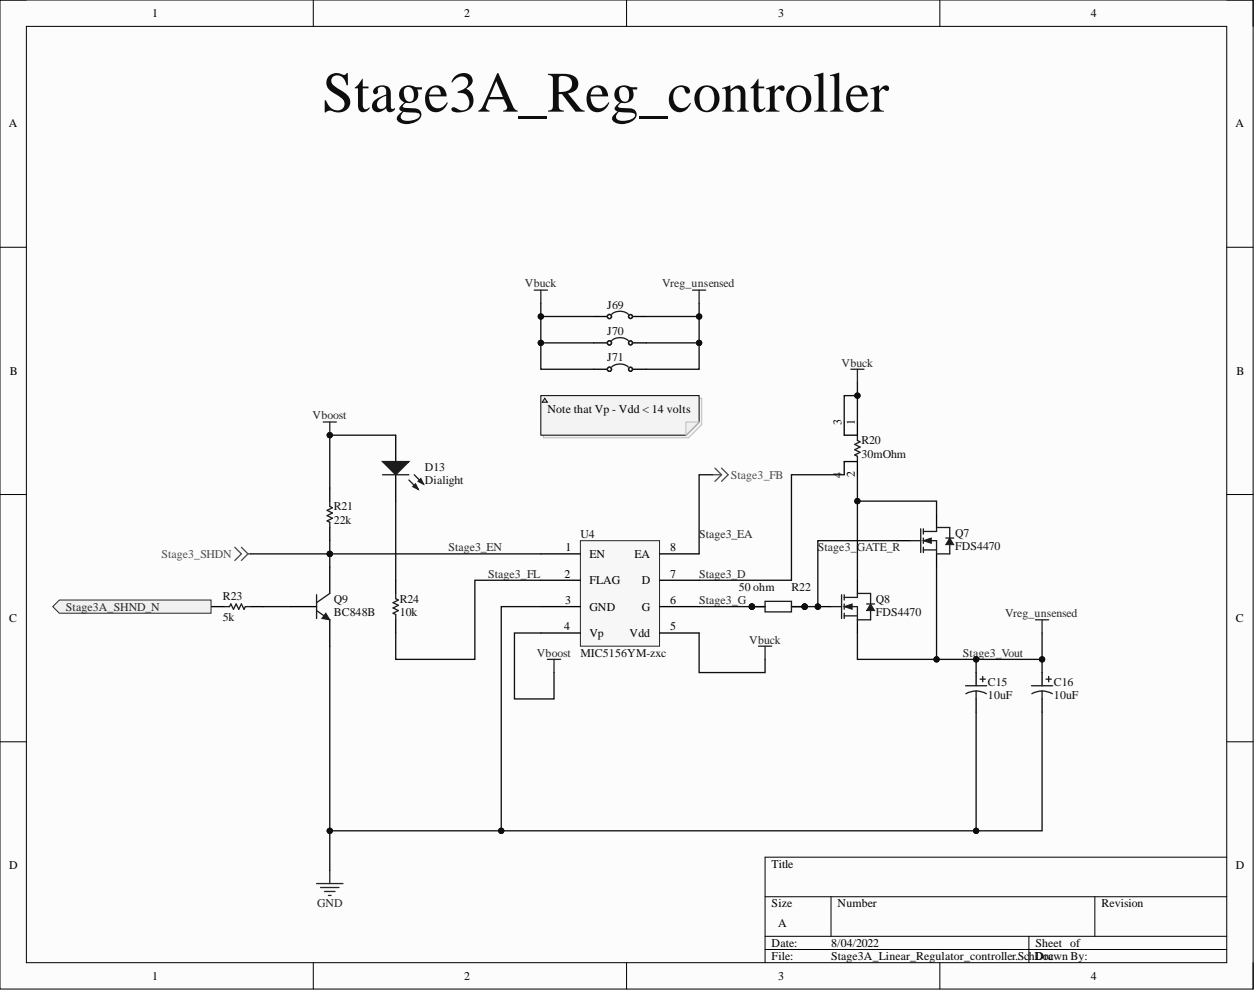
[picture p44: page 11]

Note that Vp - Vdd < 14 volts

Stage3_EA

R24 | GND 3

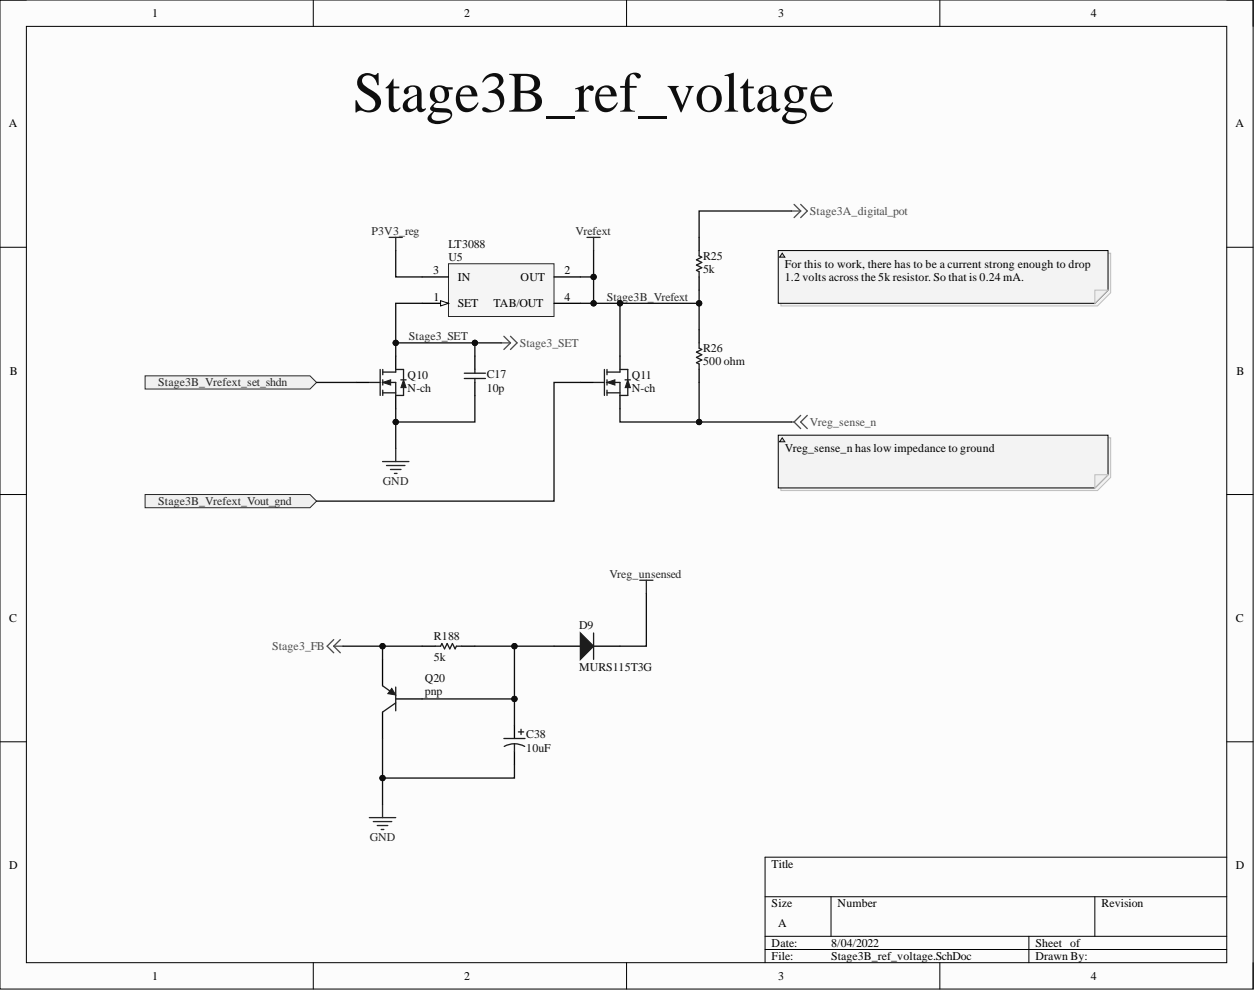
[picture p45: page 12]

For this to work, there has to be a current strong enough to drop
1.2 volts across the 5k resistor. So that is 0.24 mA.

Vreg_sense_n has low impedance to ground

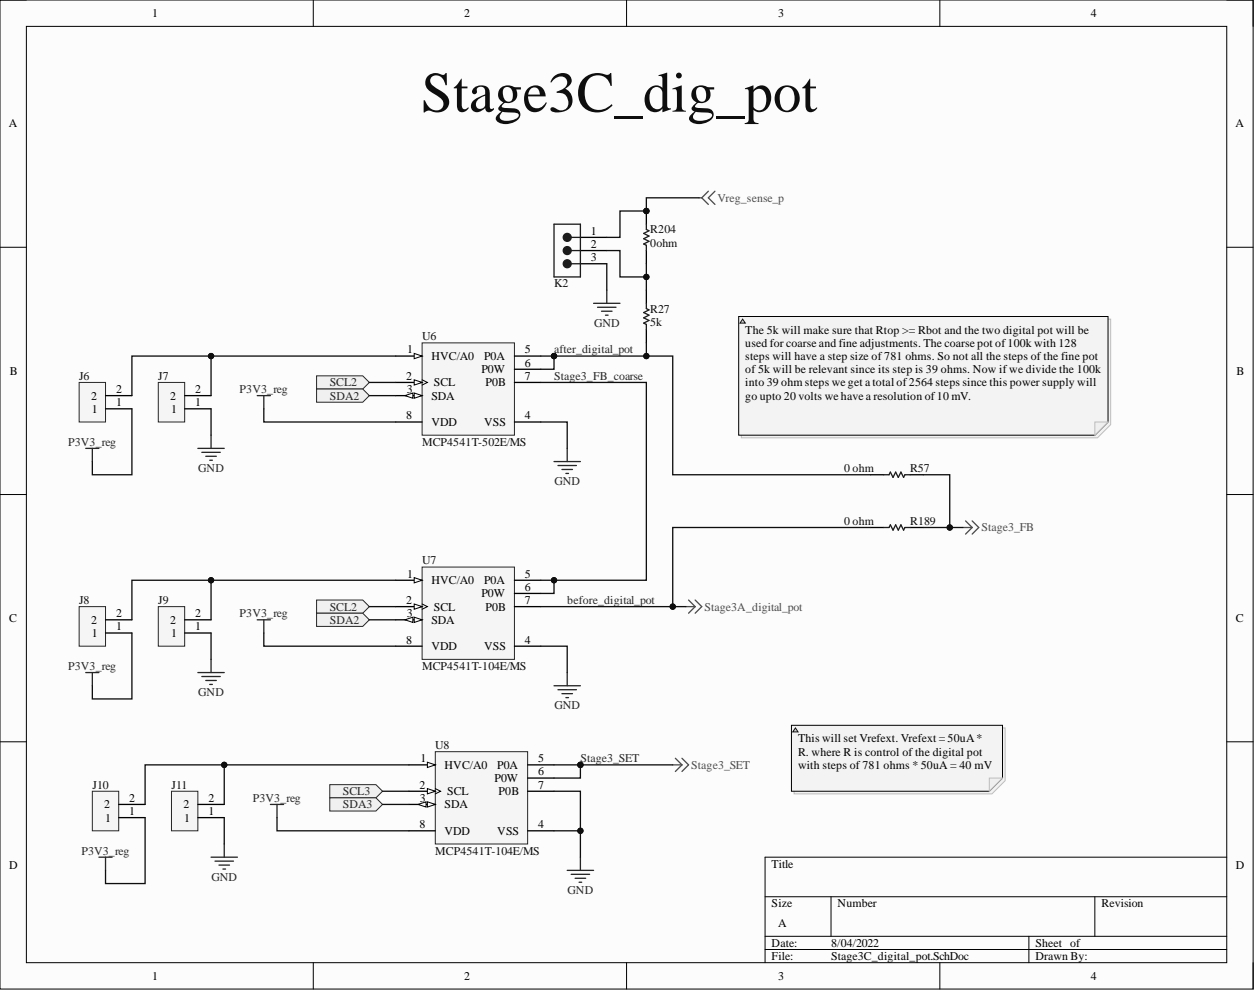
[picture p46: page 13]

The 5k will make sure that Rtop >= Rbot and the two digital pot will be
used for coarse and fine adjustments. The coarse pot of 100k with 128
steps will have a step size of 781 ohms. So not all the steps of the fine pot
of 5k will be relevant since its step is 39 ohms. Now if we divide the 100k
into 39 ohm steps we get a total of 2564 steps since this power supply will
go upto 20 volts we have a resolution of 10 mV.

This will set Vrefext. Vrefext = 50uA *
R. where R is control of the digital pot
with steps of 781 ohms * 50uA = 40 mV


We just need a 0.25mA running on the output such that there is at least a
1.2V drop on a 5k resistor.





One should select just one differential pair
going to the op-amp.







VO 3 VCC 2

GND 1


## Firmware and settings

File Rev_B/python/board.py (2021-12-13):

# -*- coding: utf-8 -*-
"""
Created on Sun Feb 18 2021

Controls the board.

EXAMPLE: 
        python board.py --port=COM3 read_voltage
        python board.py --port=COM3 read_current
        python board.py --port=COM3 calculate_load --verbose=False


REQUIREMENTS:
    python 3.7+
    pyfirmata  (to talk to the arduino)
    fire (to create command line tool)

@author: Eduardo Munoz
@email: edmugu@protonmail.com
"""
import pyfirmata
import fire
import time


class Board(object):
    """
    It controls the Arduino_Adjustable_Power_Supply module
    """

    log = ""
    version = "0.1"
    arduino_vcc = 5.0
    read_retries = 9  # The firmata library sometimes needs to reread analog voltage

    v_to_i = 1.0 / (100 * 0.1)
    power = {"in": None, "out": None}
    pins = [
        {"num": 0, "name": "Iin", "scale": v_to_i, "cur_pin": True, "value": None},
        {"num": 1, "name": "Vin", "scale": 4.56, "cur_pin": False, "value": None},
        {"num": 2, "name": "Vup", "scale": 13.74, "cur_pin": False, "value": None},
        {"num": 3, "name": "Vout", "scale": 13.74, "cur_pin": False, "value": None},
        {"num": 4, "name": "Iout", "scale": v_to_i, "cur_pin": True, "value": None},
        {"num": 5, "name": "Vdown", "scale": 31.09, "cur_pin": False, "value": None},
    ]

    def __init__(self, port="COM3"):
        print("\nboard.py version %s" % self.version)
        self.board = pyfirmata.Arduino(port)
        print("the board's firmware is version %s.%s" % self.board.firmware_version)

        # Enabling the IO
        it = pyfirmata.util.Iterator(self.board)
        it.start()
        for p in self.pins:
            self.board.analog[p["num"]].enable_reporting()
        time.sleep(0.1)

    def print(self, msg, verbose=True):
        self.log += "\n" + msg
        if verbose:
            print(msg)

    def print_lot(self):
        print(self.log)

    def read_voltage(self, verbose=True):
        """
        It reads the voltage of all the stages of the unit
        """
        self.print("reading the raw voltages\n", verbose)
        for p in filter(lambda x: x["cur_pin"] == False, self.pins):
            p["value"] = self.board.analog[p["num"]].read()
            for _ in range(self.read_retries):
                if p["value"] is not None:
                    vcc_percent = p["value"] * 100
                    p["value"] = p["value"] * self.arduino_vcc
                    self.print(
                        "Read %#04.1f%% of VCC on pin a%s (= %3.2f Volts)"
                        % (vcc_percent, p["num"], p["value"]),
                        verbose,
                    )
                    break
            if p["value"] is None:
                self.print(
                    "Read NONE on pin a%s [this might be a bug on the board's FW. run again]"
                    % p,
                    verbose,
                )
        self.print("\nCalculating the voltages on the board", verbose)
        for p in filter(lambda x: x["cur_pin"] == False, self.pins):
            if p["value"] is not None:
                p["value"] = p["value"] * p["scale"]
                self.print("%9s is %#05.2f Volts" % (p["name"], p["value"]), verbose)

    def read_current(self, verbose=True):
        """
        It reads the current going in and out
        """
        self.print("reading the raw voltages\n", verbose)
        for p in filter(lambda x: x["cur_pin"] == True, self.pins):
            p["value"] = self.board.analog[p["num"]].read()
            for _ in range(self.read_retries):
                if p["value"] is not None:
                    vcc_percent = p["value"] * 100
                    p["value"] = p["value"] * self.arduino_vcc
                    s = "Read %#04.1f%% of VCC on pin a%s (= %3.2f Volts)" % (
                        vcc_percent,
                        p["num"],
                        p["value"],
                    )
                    self.print(s, verbose)
                    break
            if p["value"] is None:
                self.print(
                    "Read NONE on pin a%s [this might be a bug on the board's FW. run again]"
                    % p,
                    verbose,
                )

        self.print("\nCalculating the voltages on the board", verbose)
        for p in filter(lambda x: x["cur_pin"] == True, self.pins):
            if p["value"] is not None:
                p["value"] = p["value"] * p["scale"]
                self.print(
                    "%9s is %#07.2f miliAmps" % (p["name"], p["value"] * 1000), verbose
                )

    def calculate_load(self, verbose=True):
        self.read_voltage(verbose=False)
        self.read_current(verbose=False)
        self.print("Calculating the load on the output\n", verbose)

        pvout = list(filter(lambda x: x["name"] == "Vout", self.pins))[0]["value"]
        piout = list(filter(lambda x: x["name"] == "Iout", self.pins))[0]["value"]

        if (pvout is None) or (piout is None):
            self.print("had issues reading voltage or current", verbose)
            return
        ans = pvout / piout
        self.print("Rload is %05.2f\n" % ans, verbose)

    def calculate_power(self, read_tries=99):
        self.calculate_load(verbose=False)
        vin = list(filter(lambda x: x["name"] == "Vin", self.pins))[0]["value"]
        iin = list(filter(lambda x: x["name"] == "Iin", self.pins))[0]["value"]
        vout = list(filter(lambda x: x["name"] == "Vout", self.pins))[0]["value"]
        iout = list(filter(lambda x: x["name"] == "Iout", self.pins))[0]["value"]

        self.power["in"] = vin * iin
        self.power["out"] = vout * iout

        self.print("Power in : %7.3f Watts" % self.power["in"])
        self.print("Power out: %7.3f Watts" % self.power["out"])

    def calculate_efficiency(self, read_tries=99):
        self.calculate_power()
        efficiency = self.power["out"] / self.power["in"]
        self.print("Efficiency: %4.1f %% " % efficiency)


if __name__ == "__main__":
    fire.Fire(Board)

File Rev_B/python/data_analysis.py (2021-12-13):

# -*- coding: utf-8 -*-
"""
Created on Sun May 18 2021

Simple data analysis script



@author: Eduardo Munoz
@email: edmugu@protonmail.com
"""
import matplotlib.pyplot as plt
import pandas as pd
import os

dir1 = "../measurements/"


for filename in os.listdir(dir1):
    if filename.endswith(".csv"):
        file = dir1 + filename
        df = pd.read_csv(file)
        
        fig, ax1 = plt.subplots()
        color = 'tab:blue'
        x = list(df["Iout_meas [A]"])
        y = list(df["Iin_meas [A]"])
        plt.plot(x, y, color=color)
        plt.suptitle(file)
        plt.title("Iin and Vout vs Iout")
        plt.xlabel("Iout [Amps]")
        plt.ylabel("Iin [Amps]", color=color)
        plt.axhline(y=1.0, color="black")
        
        ax2 = ax1.twinx()  # instantiate a second axes that shares the same x-axis
        
        y = list(df["Vout_meas [V]"])
        x = list(df["Iout_meas [A]"])
        
        color = 'tab:red'
        plt.plot(x, y, color=color)
        plt.ylabel("Vout [Volts]", color=color)
        
        
        plt.savefig(file + ".png")

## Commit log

2021-12-13 fresh restart
    [LDO_measurements.csv, amp-diff.txt, diff.txt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]
2021-12-15 removes temperature steps
2021-12-16 max current @ 18V calculations
2021-12-16 Reduces the SHDN_N current
2021-12-16 Adds the power of the reference regulator and controller
2021-12-16 switches 36V to Vwanted + 2
2021-12-16 Removes redundant regulator
2021-12-16 Adds abs commands to the power calculations
2021-12-16 Adds series resistance
2021-12-16 removes "heat" text
2021-12-17 made the capacitor "chunkier"
2021-12-17 Cleaned the schematics
2021-12-20 removes resistance plot
2021-12-20 updated resistors to match voltage levels
2021-12-22 Renamed folder
    [Stage_1_Boost_controller.xls]
2021-12-22 Updated vout to 21.5V
    [Stage_1_Boost_controller.xls]
2021-12-28 adds pin sel
2021-12-30 Fixes reference voltage
2022-01-02 Adds simpler voltage reference model
2022-01-08 Revert "Update Stage_3_Regulator_controller.asc"
    This reverts commit 1b9bb1c76eff58444322fe5e731eb5236a51bf96.
2022-01-08 changed IC name to correct name
    [Stage_0.fzz]
2022-01-09 changed the prototype to one with breadboard like pattern
    [Stage_0.fzz]
2022-02-18 Adds power filter study
2022-02-24 encoder pictures added
2022-04-12 Updates PCB files
2022-04-28 Shrinks PCB to size for the case
2022-07-05 PCB files updated
2022-07-25 Fixes the Stage 1 inj_transformer
2022-07-28 Updates stage 3 for inj transformer
